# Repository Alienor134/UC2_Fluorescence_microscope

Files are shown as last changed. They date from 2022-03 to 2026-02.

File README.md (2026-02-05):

# Fluorescence microscope adapted with UC2 library





An open-source, modular LED-based fluorescence microscope with infinity optics. This system is capable of acquiring time-lapse videos from living cells inside an incubator and supports X/Y/Z/t acquisitions and fluorescent imaging.

**Intended Audience**: Researchers, engineers, microscopists interested in reducing the cost of hardware development for optical systems and produce quick prototypes. 

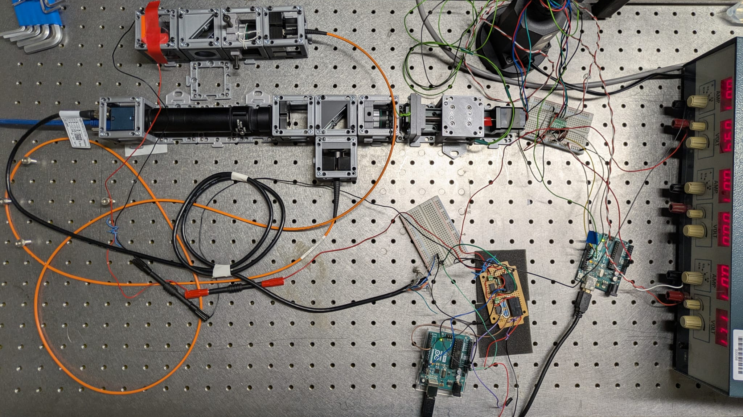
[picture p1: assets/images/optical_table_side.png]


## Documentation

Access the full [documentation website](https://alienor134.github.io/UC2_Fluorescence_microscope/docs)

## Repository Structure

- **Hardware**: CAD files in `INVENTOR/` (source) and `STL/` (3D printing). Specific hardware ca also be found in the submodules, in particular for different motorization options 
- **Software**: Control modules as Git submodules (`ControlCamera`, `ControlLight`, `ControlMotors`, `ControlSerial`)
- **Documentation**: Build guides, automation, and bills of materials in `docs/`

## Quick Start

```bash
# Clone the repository with submodules
git clone https://github.com/Alienor134/UC2_Fluorescence_microscope.git
cd UC2_Fluorescence_microscope
git submodule update --init --recursive
```

The instrument can run without specific software except the camera. The LED control and motor control are optional and can be replaced by manual actions. Still, for detailed setup instructions of the software, see [docs/automate.md](docs/automate.md)

---

## Interested in contributing to the project ? Read the following.

This project follows the [Open Source Hardware Association (OSHWA) definition](https://www.oshwa.org/definition/) of open-source hardware. All design files, documentation, and bills of materials are freely available. Modifications and derivatives are encouraged under the terms of the CERN-OHL-S-2.0 license.

If any file missing, raise an issue in Gtihub repository and we will address it.

### Licenses

#### Hardware License
The hardware designs (CAD files, STL files, and mechanical assemblies) are licensed under the **CERN Open Hardware Licence Version 1 (CERN-OHL-S-1.2)**. See [LICENSE](License.md) for full text. The license is inherited from the OpenUC2 project.

#### Software License
The control software modules are licensed under the **GNU General Public License v3.0 (GPL-3.0)** or later. See individual LICENSE files in each submodule directory.

#### Documentation License
Documentation is licensed under **Creative Commons Attribution-ShareAlike 4.0 International (CC BY-SA 4.0)**.

### Version Control Practice

- **Repository**: Git-based version control with full commit history
- **Submodule Structure**: This module is part of the UC2 Fluorescence Microscope parent repository
- **Versioning**: Semantic versioning (MAJOR.MINOR.PATCH)
- **Releases**: Archived on Zenodo

### Attribution Requirements

When using or modifying this software:

1. **Credit the original authors**: Aliénor Lahlou, Sony Computer Science Laboratories
2. **Maintain license notices**: Keep license-related headers in source files
3. **Document modifications**: Clearly state any changes made
4. **Share derivatives**: Derivatives must be released compatible license

### Contributing

Contributions are tracked through:
- Git commit history (automatic attribution)
- Pull requests on GitHub
- Contributor acknowledgments in release notes

The documentation is automatically generated via Github Pages and should be updated along modifications (folder [docs](https://github.com/Alienor134/UC2_Fluorescence_microscope/tree/main/docs)). Follow these [instructions](https://docs.github.com/en/pages/setting-up-a-github-pages-site-with-jekyll/testing-your-github-pages-site-locally-with-jekyll) to verify the changes locally before commit. 

--- 

## Current version

- **Current Version**: 1.0.0
- **Last Updated**: January 2026
- **Git Repository**: https://github.com/Alienor134/UC2_Fluorescence_microscope
- **Zenodo DOI**: https://doi.org/10.5281/zenodo.18483954

## Citation

If you use this microscope design in your research, please cite it properly. We have registered this project on Zenodo for permanent archival with a persistent DOI (https://doi.org/10.5281/zenodo.18483954).

## Acknowledgments

This project builds upon several open-source initiatives:

### Hardware Acknowledgments
- **[OpenUC2](https://github.com/openUC2/UC2-GIT)**: Base modular cube system and optical components.

### Software Acknowledgments
- **[pymmcore-plus](https://pymmcore-plus.github.io/pymmcore-plus/)** to facilitate working with Micro-manager backend in pure Python/C environments.
- **[ROMI project](https://github.com/romi)** (Sony CSL) providing open-source tools to control hardware with Arduino and Python.
- **[Sacred](https://github.com/IDSIA/sacred)** to organise automated experimental runs. 

## Attributions

This project is based on the [UC2 fluorescence microscope](https://github.com/openUC2/UC2_Fluorescence_microscope?tab=readme-ov-file) by OpenUC2, licensed under CERN-OHL-S v2.   
**Modifications**: light source (from laser to LED), motorized focus, software.
**Additions**: dual illumination, optical fiber injection, data management.

*This project is open-source and released under CERN-OHL-S-2.0 (hardware) and GPL-3.0 (software) licenses.*

---

## Cross-References and Navigation

### UC2 Fluorescence Microscope Project

- **Main Repository**: [UC2_Fluorescence_microscope](https://github.com/Alienor134/UC2_Fluorescence_microscope)
- **Documentation Home**: https://alienor134.github.io/UC2_Fluorescence_microscope/docs/
- **Build Instructions**: https://alienor134.github.io/UC2_Fluorescence_microscope/docs/build
- **Bill of Materials**: https://alienor134.github.io/UC2_Fluorescence_microscope/docs/bill_of_materials
- **Automation Guide**: https://alienor134.github.io/UC2_Fluorescence_microscope/docs/automate
- **Examples**: https://alienor134.github.io/UC2_Fluorescence_microscope/docs/example

### Related Control Modules

| Module | Purpose | Documentation |
|---|---|---|
| [ControlCamera](https://github.com/SonyCSLParis/ControlCamera) | Camera acquisition and control | [README](https://github.com/SonyCSLParis/ControlCamera/README.md) |
| [ControlLight](https://github.com/SonyCSLParis/ControlLight) | Laser and LED control | [README](https://github.com/SonyCSLParis/ControlLight/README.md) |
| [ControlMotors](https://github.com/SonyCSLParis/ControlMotors) | XYZ stage and motor control | [README](https://github.com/SonyCSLParis/ControlMotors/README.md) |
| [ControlSerial](https://github.com/SonyCSLParis/ControSerial)| Arduino-Python communication | [README](https://github.com/SonyCSLParis/ControSerial/README.md) |
| [Altar](https://github.com/DreamRepo/Altar) | Data management and visualization | [Documentation](https://dreamrepo.github.io/Altar/) |

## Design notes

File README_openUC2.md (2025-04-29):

<p align="left">

</p>

# openUC2 Fluorescence Microscope (infinity)
---

This is the repository for the laser-based fluorescence microscope with infinity optics. It is capable to acquire Time-Lapse videos from living cells inside an incubator.

The current version of the Z-stage is inspired by the flexure-bearing Z-stage from Richard Bowman's openflexure microscope design. Their open-source project can be found [here](https://openflexure.org). We also emphasize to use the [delta stage](https://openflexure.org/projects/deltastage/) where [UC2 provides an adapter](https://github.com/openUC2/UC2-GIT/tree/master/CAD/ASSEMBLY_CUBE_Openflexure_Deltastage) for our system.

The setup looks as follows:

<p align="center">
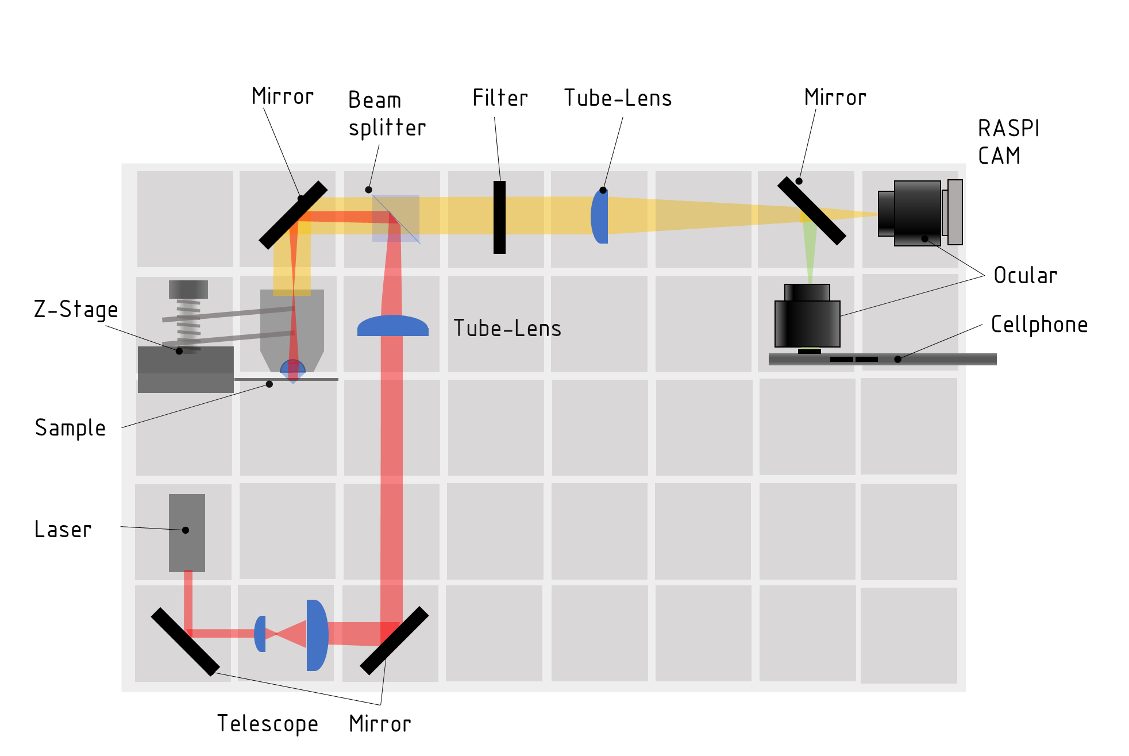
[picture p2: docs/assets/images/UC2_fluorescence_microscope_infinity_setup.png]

</p>

We use a high power entertainment laser to excite a specific fluorophore, where the emission signal is either filtered by a proper dichroic mirror cube (dichroic+filter) or a low-cost version of a simple 50/50 beamsplitter and an emission filter. The setup uses infinity optics and can either be used with a bare chip or a combination of cellphone camera (with lens) and an eyepiece to achieve proper imaging.

It is a very early developer version. Please feel free to contribute to the documentation and device development.

*Note:* The pictures on this site do not show the latest version of the Z-stage. Follow the respective assembly guidelines.

<p align="center">
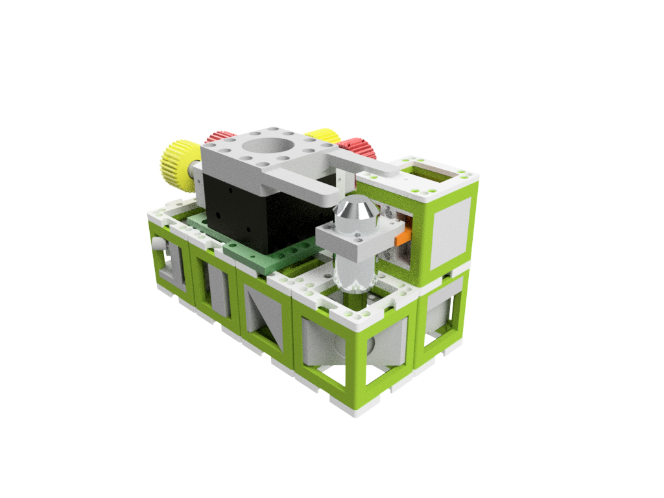
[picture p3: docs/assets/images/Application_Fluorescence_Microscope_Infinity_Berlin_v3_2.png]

</p>

***Features:***

* X/Y/Z/t Acquisitions possible
* Fluorescent imaging
* Quantitative Phase Imaging
* Modularized design
* Low-cost acquisition
* Based on off-the-shelf components
* Open-Source
* infinity corrected optics
* use of low-cost CMOS sensors possible

# Software
🢂 Find the software for this setup in our dedicated [UC2-Software-GIT](https://github.com/bionanoimaging/UC2-Software-GIT)

# Hardware

Below we describe how the device can be build and assembled in order to replicate the whole system as shown in the rendering above. One needs additional parts that can be found in the core [openUC2 repository](https://github.com/bionanoimaging/UC2-GIT).

### Parts for this setup

<p align="center">
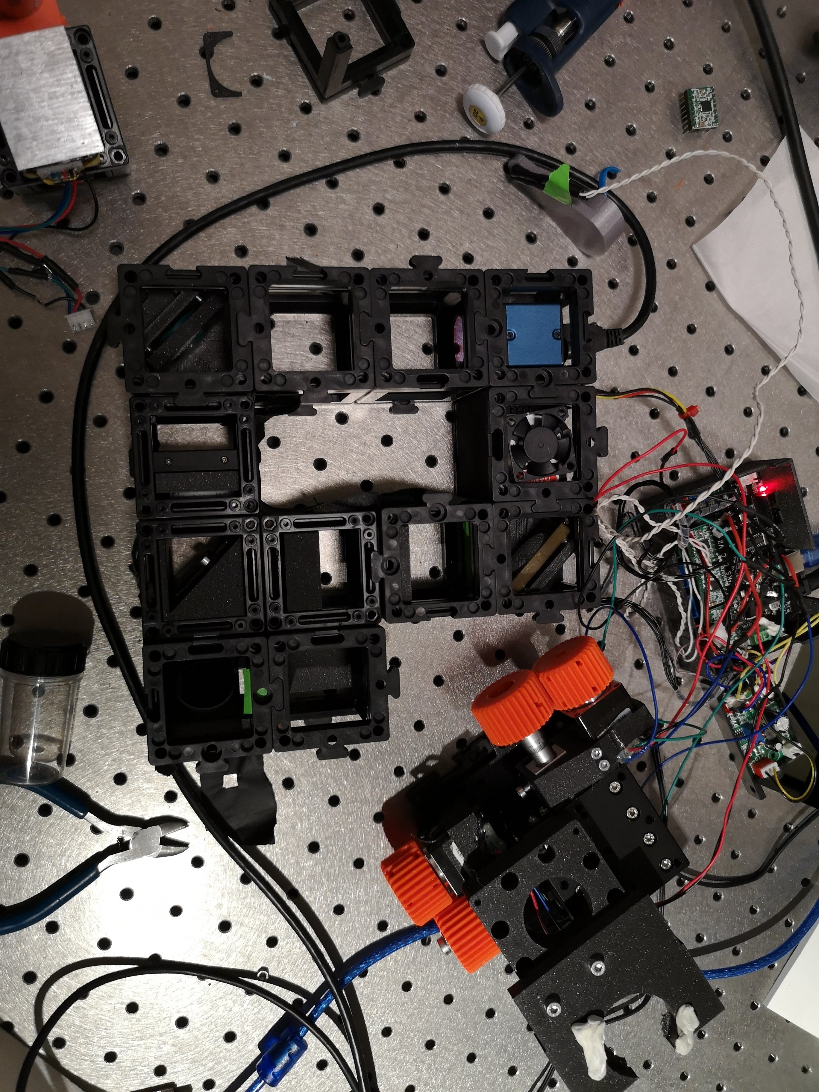
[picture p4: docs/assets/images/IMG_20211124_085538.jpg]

</p>

| Amount | Type  | Properties | Price | Source |
|----|----|----|----|----|
| 1 | Camera | Daheng Imaging MER2-230-168U3M | 500 € | Daheng Imaging [Link](https://www.machinevisionkamera.de/USB3-Bildverarbeitungskamera-2.3MP-Monochrome-Sony-IMX174-MER2-230-168U3M)|
| 1  | Camera | USB ALVIUM 1800 U -158 | 333 € | Allied Vision [Edmund Optics](https://www.edmundoptics.de/p/allied-vision-alvium-1800-u-158m-129-16mp-s-mount-usb-31-monochrome-camera/42981/) |
| 1 | Laser | 1× Laser Module, 635/637nm entertainment laser (laserlands.net, #3450, Dot Laser Module, 300mW, 50 Euro, China)  | 60 €| [Laserlands.net](https://www.laserlands.net/638nm-laser-500mw-laser-module-red-light-laser.html)|
| 1 | Emission Filter (we used on old Chroma, QE690/55!) | Thorlabs FEL0650 | 78 € | [Thorlabs](https://www.thorlabs.com/thorproduct.cfm?partnumber=FEL0650) |
| 1 | Dichroic Mirror | DMLP650 | 250 € | [Thorlabs](https://www.thorlabs.com/thorproduct.cfm?partnumber=DMLP650) |
| 1 | Shortpass Filter (cleanup)  | FES0650 | 78 € | [Thorlabs](https://www.thorlabs.com/thorproduct.cfm?partnumber=FES0650) |
| 2 | Mirrors 1 inch | Silver, protected mirror | 50 € | [Thorlabs](https://www.thorlabs.com/thorproduct.cfm?partnumber=PF10-03-P01) |
| 1 | Tube lense according to objective lens (imaging-side) | 80 mm for Allied Vision, 150 for Daheng Imaging, Achromat | 96 € | [Thoralbs](https://www.thorlabs.de/thorproduct.cfm?partnumber=AC254-080-A-ML)/[Thoralbs](https://www.thorlabs.de/thorproduct.cfm?partnumber=AC254-150-A-ML) |
| 1 | Tube Lens (illumination-side) | Achromat, f 156,4mm / ∅40,0mm  or  f 150 mm / ∅25,4mm | 5,9 € / 96 € | [PGI-Versand](https://astro-didaktik.de/achromat-2-linser-o-40-mm-f-156-4-mm.html)/[Thoralbs](https://www.thorlabs.de/thorproduct.cfm?partnumber=AC254-150-A-ML) |
| 1 | M3 Screws, DIN ISO 912, various (buy a set) | | ? | Würth |
| 1 | Microscope Objective lens | 1x Objective lens, No Name, 100x, NA1.25, 50 Euro, China | 100 € | [Aliexpress](https://de.aliexpress.com/item/4000200609554.html) |
| 1 | Beam Splitter Dichroic (Discontinued?) | Comar optics Dichro 740 IY als 45° | 40 € | Comar  |
| 1 | Filter Emission (Discontinued?) | Emissionsfilter 655 IY als 0° | 40 € | Comar |
| 200  | Magnets  | 5mm Ball Magnets, NEoxym  | 0,31 | [Magnetmax](https://www.magnetmax.de/Neodym-Kugelmagnete/Magnetkugel-Kugelmagnet-O-5-0-mm-Neodym-vernickelt-N40-haelt-400-g::158.html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) || 4 | Mirrors 1 inch | Thoralbs | ~50 | [Thorlabs](https://www.thorlabs.com/thorproduct.cfm?partnumber=PF10-03-P01) |  1x500 | Screws M3x12 | | ?  | [Würth](https://eshop.wuerth.de/Zylinderschraube-mit-Innensechskant-SHR-ZYL-ISO4762-88-IS25-A2K-M3X12/00843%20%2012.sku/de/DE/EUR/)

Find the complete [Bill-of-Materials here](UC2_Microscope_BillOfMaterial_STORM.xlsx)

## Modules

|  Name | Properties  |  Price | Link  | # |
|---|---|---|---|---|
|  Baseplate puzzle| - | 5€  | [Base-plate](https://github.com/openUC2/UC2-GIT/tree/master/CAD/ASSEMBLY_Baseplate/)  | ~20|
|  Module: Z-Stage | - | ?? €  | [Z-Stage](https://github.com/openUC2/UC2-GIT/tree/master/CAD/ASSEMBLY_CUBE_Z-STAGE_NEMA_MGN)  | 1|
| (Alternative) [Delta stage](https://openflexure.org/projects/deltastage/)  | Openflexure | ?? €  | [Deltastage](https://github.com/openUC2/UC2-GIT/tree/master/CAD/ASSEMBLY_CUBE_Openflexure_Deltastage)  | 1|
|  Module: Kinematic Mirror 45°  (THORLABS!) | - | 5€  | [Kinematic Mirror 45](https://github.com/openUC2/UC2-GIT/tree/master/CAD/ASSEMBLY_CUBE_Mirror_Kinematic_45)  | 2 |
|  Module: Alvium CMOS Camera  | Low-Cost Camera | 5€  | [Alvium Camera](https://github.com/openUC2/UC2-GIT/tree/master/CAD/ASSEMBLY_CUBE_AlliedVision_Alvium)  | 1|
| Alternative (better) Daheng Imaging IMX174 | SMLM Camera | 5€  | [Alvium Camera](https://github.com/openUC2/UC2-GIT/tree/master/CAD/ASSEMBLY_CUBE_AlliedVision_Alvium)  | 1 |
|  Module: Beamsplitter (dichroic)  | - | ??€  | [Dichroic Beam splitter](https://github.com/openUC2/UC2-GIT/tree/master/CAD/ASSEMBLY_CUBE_Dichroic_Beamsplitter)  | 1|
|  Module: Thorlabs + Lens (160mm, 80mm) | - | 5€  | [Thorlabs Insert](https://github.com/openUC2/UC2-GIT/tree/master/CAD/ASSEMBLY_CUBE_Thorlabs)  | 2 |
|  Module: Laser (Block) | - | 5€  | Just mount the laser on the insert using screws. | 2 |
|  Module: 45° Mirror  (Thorlabs) | - | 5€  | [Mirror](https://github.com/openUC2/UC2-GIT/tree/master/CAD/ASSEMBLY_CUBE_Mirror_45)  | 2 |

### Variants

We use various different XY Stages:

[**1. Micrometer XY-stage**](https://github.com/openUC2/UC2-MicronStage)

[**2. Aliexpress Microscop XY-stage**](https://github.com/openUC2/UC2-Motorized-XY-Table)

**3. Openflexure Stage**

### Electronics
🢂 Find more in the [Electronics section](https://github.com/openUC2/UC2-GIT/tree/master/ELECTRONICS)

## Setup variants

**Assembled Setups with a Jetson-driven mono camera:**

For more infos about the camera look [here](https://github.com/openUC2/UC2-GIT/tree/master/CAD/ASSEMBLY_CUBE_AlliedVision_Alvium)

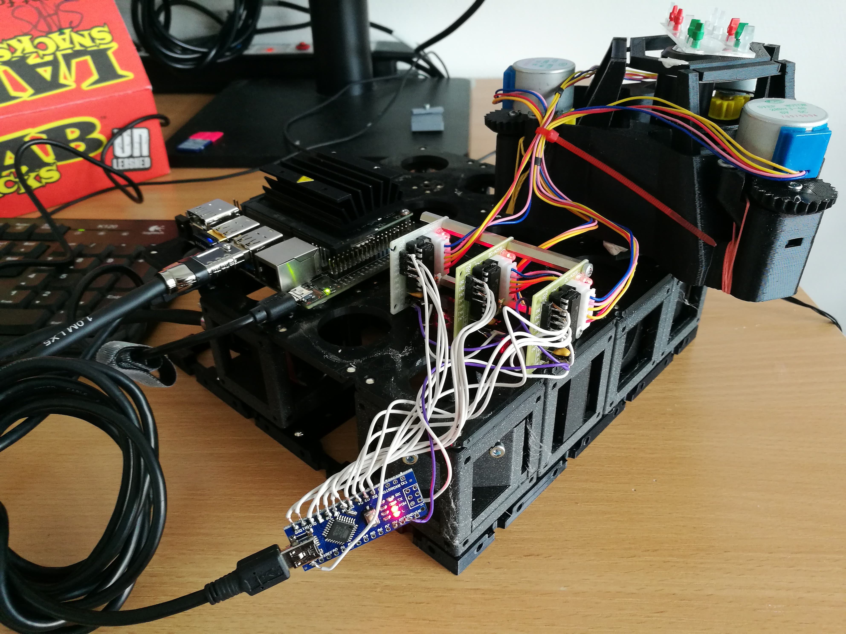
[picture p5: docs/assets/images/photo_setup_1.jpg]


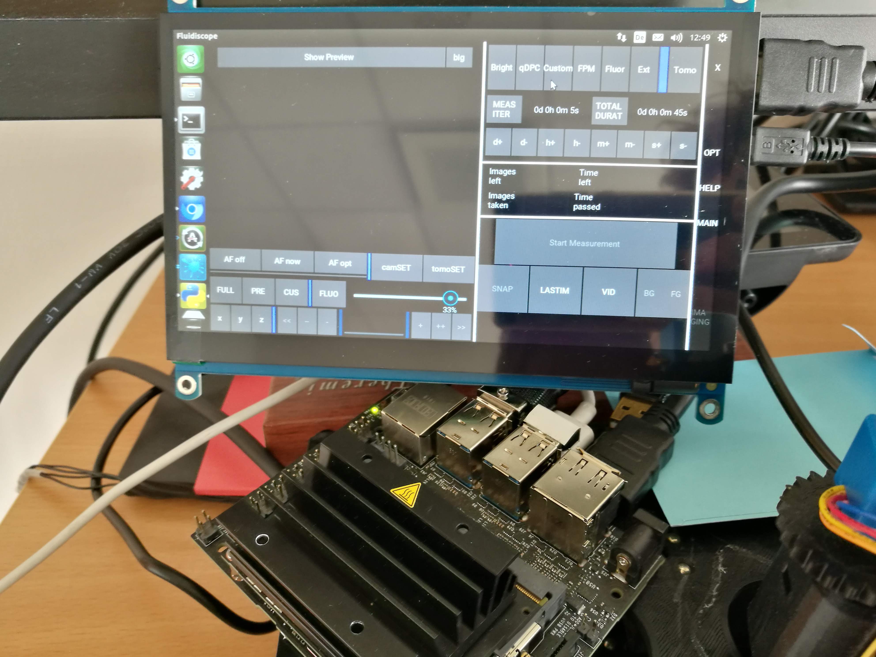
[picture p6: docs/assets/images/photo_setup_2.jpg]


## Setup

**Side View:**



**Top View:**

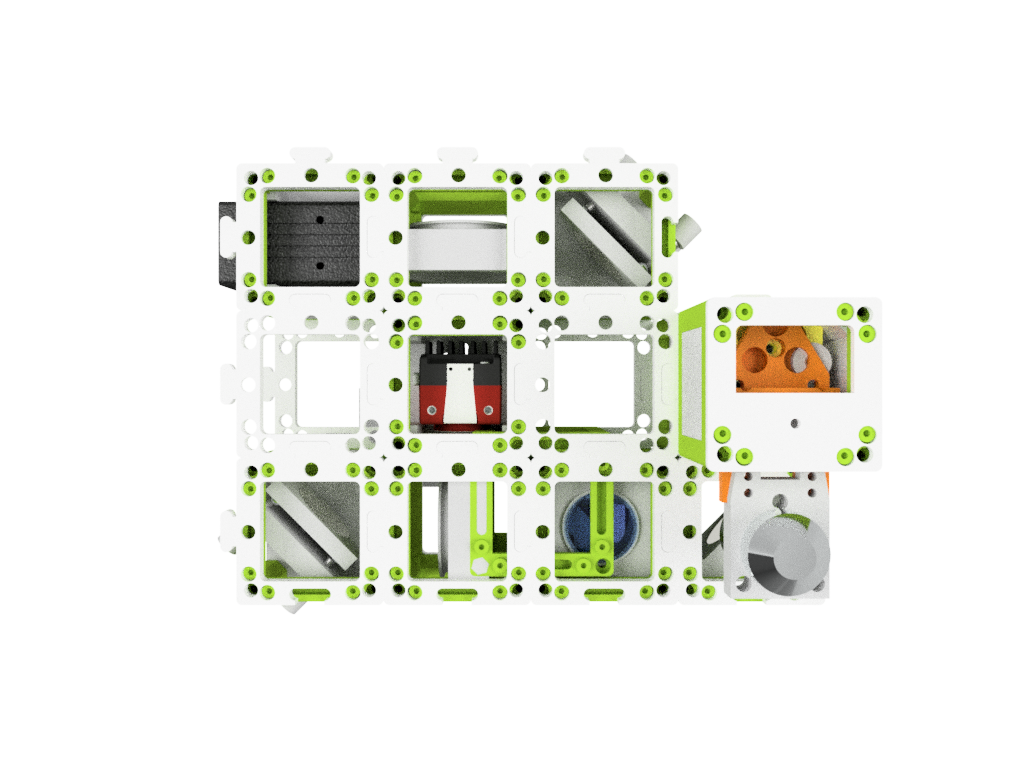
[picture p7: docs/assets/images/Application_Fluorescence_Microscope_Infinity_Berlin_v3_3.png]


**Backside View:**

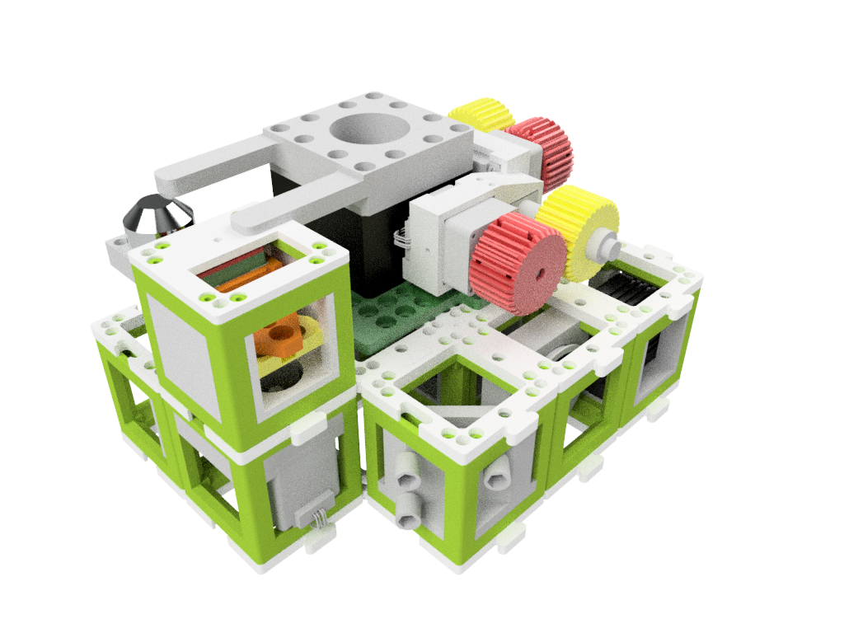
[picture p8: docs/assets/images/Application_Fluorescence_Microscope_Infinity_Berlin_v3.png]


**Find a little [Tutorial on how to make it work here](Tutorial.md)**

## Showcase
This is a set of ATTO 647 labelled *e.colis* provided by O. Helle from UiO imaged with a 100x, 1.25, a cellphone (Huawei P20 Pro, monochromatic camera, Freedcam) and a 635/637 nm exciation.

<p align="center">
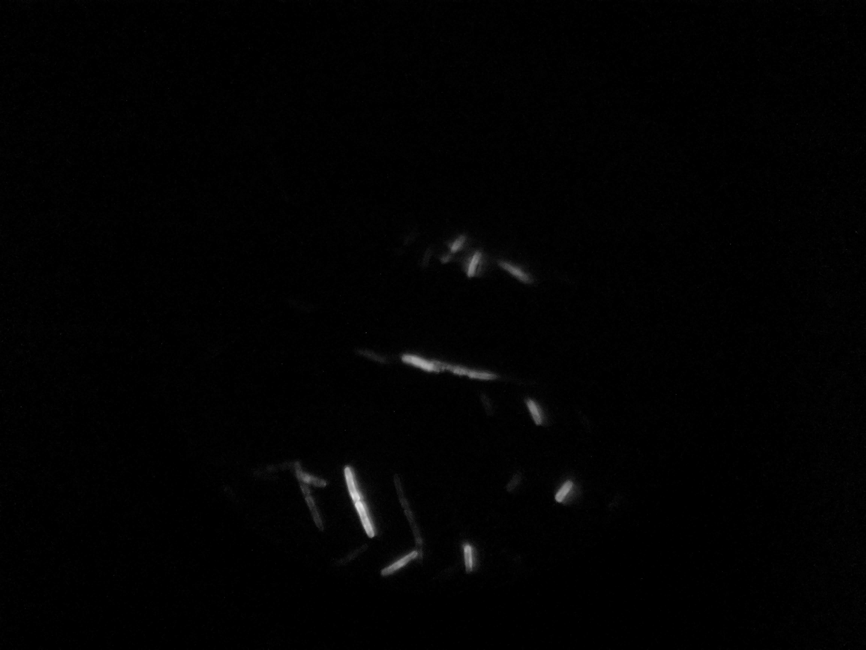
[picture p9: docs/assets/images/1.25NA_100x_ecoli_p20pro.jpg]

</p>

This is acquired with the Allied Vision Alvium 1500-158 and the new UC2 Nvidia Jetson Nano GUI. HeLa labelled with Alexa Fluor 647 Phal.

***Brightfield***
<p align="center">
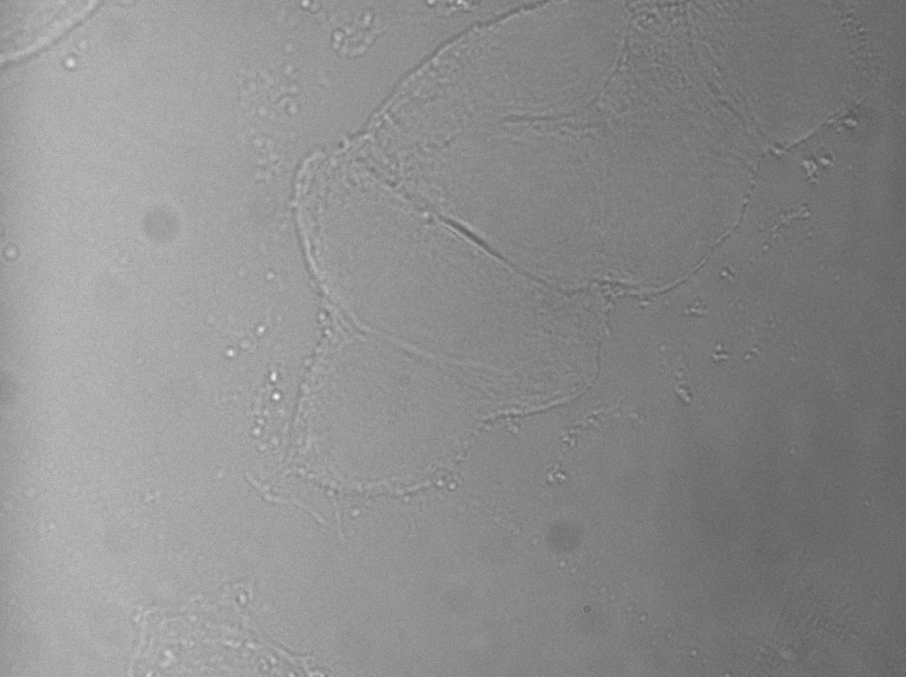
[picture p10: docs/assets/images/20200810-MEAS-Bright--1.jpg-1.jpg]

</p>

***Fluorescence***
<p align="center">
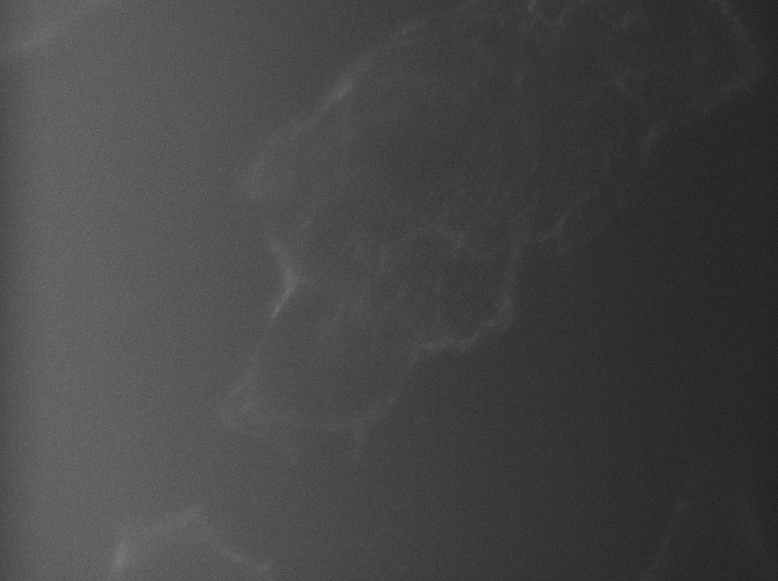
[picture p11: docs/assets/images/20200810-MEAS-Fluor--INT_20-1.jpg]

</p>

***Overlay***
<p align="center">
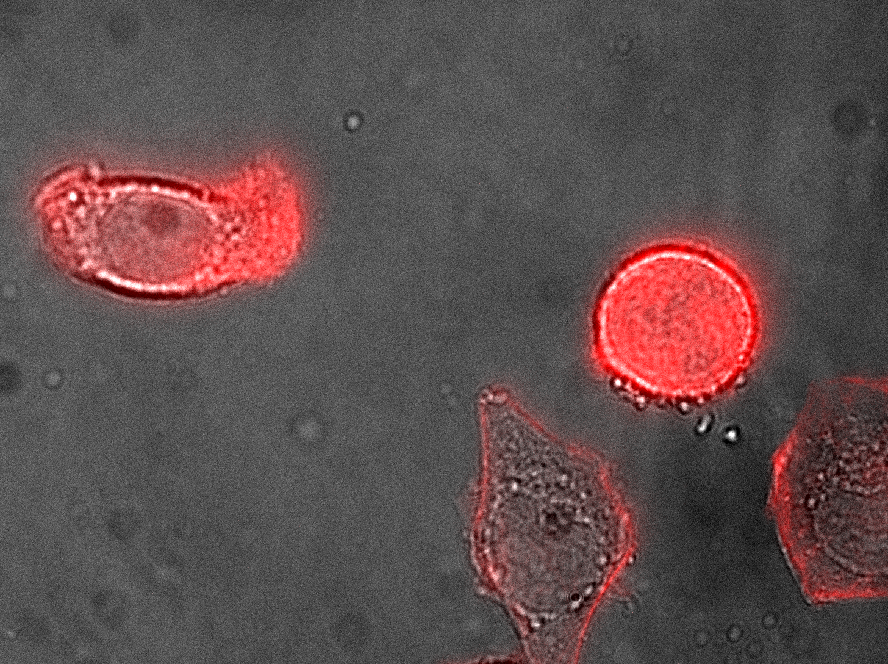
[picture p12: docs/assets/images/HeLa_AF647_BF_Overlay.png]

</p>

***Optical Setup***
<p align="center">

</p>

***ImSwitch Control Software***
<p align="center">
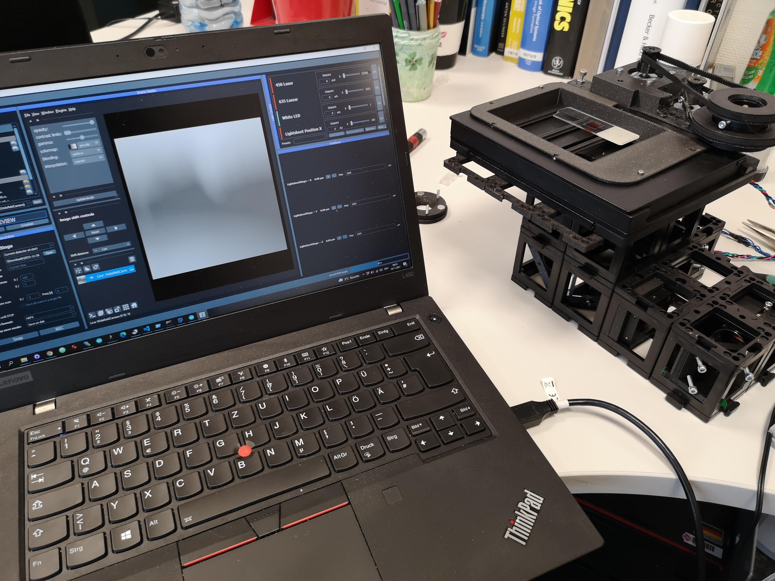
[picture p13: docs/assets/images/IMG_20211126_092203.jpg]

</p>

***SMLM Sample Holder***
<p align="center">
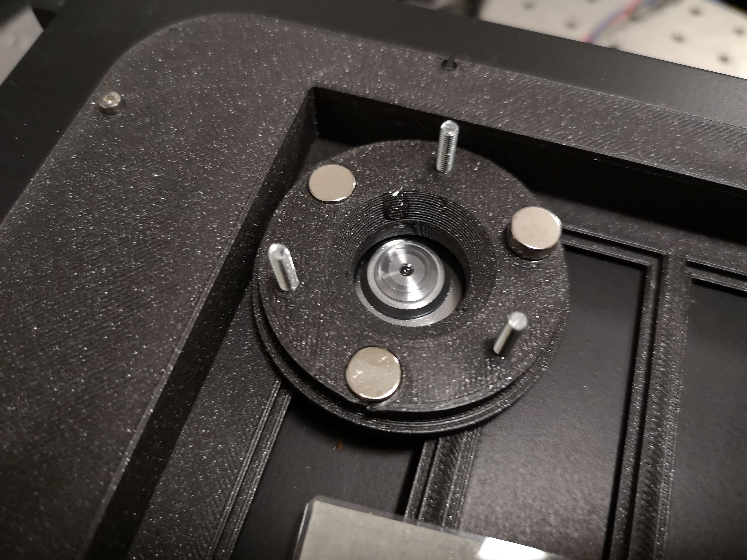
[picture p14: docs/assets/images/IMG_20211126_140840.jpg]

</p>

## Get Involved

This project is open-source so that anyone can get involved. You don't even have to learn CAD designing or programming. Find ways you can contribute in  [CONTRIBUTING](https://github.com/openUC2/UC2-GIT/blob/master/CONTRIBUTING.md)

## License and Collaboration

This project is open-source and is released under the CERN open hardware license. Our aim is to make the kits commercially available.
We encourage everyone who is using our Toolbox to share their results and ideas, so that the Toolbox keeps improving. It should serve as a easy-to-use and easy-to-access general purpose building block solution for the area of STEAM education. All the design files are generally for free, but we would like to hear from you how is it going.

You're free to fork the project and enhance it. If you have any suggestions to improve it or add any additional functions make a pull-request or file an issue.

Please find the type of licenses [here](https://github.com/openUC2/UC2-GIT/blob/master/License.md)

REMARK: All files have been designed using Autodesk Inventor 2019 (EDUCATION)

## Collaborating
If you find this project useful, please like this repository, follow us on Twitter and cite the webpage! :-)

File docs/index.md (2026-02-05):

---
layout: default
title: Introduction
nav_order: 1
---

# Introduction

 Reference: *Minimal reproduction and calibration of a fluorescence microscope for single-cell imaging*


*Picture of the final set-up*

> Source code: [UC2_Fluorescence_microscope on GitHub](https://github.com/Alienor134/UC2_Fluorescence_microscope)

## Navigation
- [Introduction](index.md)
- [Bill of Materials](bill_of_materials.md)
- [Build Instructions](build.md)
- [Software](automate.md)

---

# Purpose

Microscopy is a critical experimental tool in life sciences. However, when attempting to reproduce or scale-up a published method, researchers often meet difficulties in implementing specific protocols, often because they do not have full control over the hardware and software. 

To address these challenges, we present a modular open-source hardware and software pipeline that integrates automation and database management. 

We provide comprehensive guidance on building and calibrating the microscope hardware, implementing automation, and data analysis and storage methods. The highly modular Python software we introduce facilitate customization and reusability beyond microscopy, empowering researchers and engineers to adapt components for other scientific applications.

The microscope presented here is a simplified and open-source version of the microscope used in [this publication](https://doi.org/10.1101/2025.01.23.633867). The 3D structure was derived from the [Open-UC2](https://openuc2.com/) library.

In this repository we provide: 
- A [bill of materials](bill_of_materials.md) to reproduce the microscope 
- [Build instructions](build)
- Python packages to use the library: they each have their specific documentation
- [Software](automate.md) summary with support codes

# License

**Hardware License**

The hardware designs (CAD files, STL files, and mechanical assemblies) are licensed under the CERN Open Hardware Licence Version 1.2 (CERN-OHL-S-1.2). See LICENSE for full text.

**Software License**

The control software modules are licensed under the GNU General Public License v3.0 (GPL-3.0) or later. See individual LICENSE files in each submodule directory.

**Documentation License**

Documentation is licensed under Creative Commons Attribution-ShareAlike 4.0 International (CC BY-SA 4.0).

# Attributions

This project is based on the [UC2 fluorescence microscope](https://github.com/openUC2/UC2_Fluorescence_microscope?tab=readme-ov-file) by OpenUC2, licensed under CERN-OHL-S v2.   
**Modifications**: light source (from laser to LED), motorized focus, software.
**Additions**: dual illumination, optical fiber injection, data management.
The original authors do not endorse this version.

# Contributing

The guidelines to contribute to the project (including versionning and attribution statements) are listed in the [README](https://github.com/Alienor134/UC2_Fluorescence_microscope/blob/main/README.md) page of this project.

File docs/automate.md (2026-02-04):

# Software

thumbnails

## Summary of the available software

[ControlSerial](https://github.com/Alienor134/UC2_Fluorescence_microscope) - Python serial interface  
[ControlMotors](https://github.com/Alienor134/UC2_Fluorescence_microscope) - Motor control  
[ControlCamera](https://github.com/Alienor134/UC2_Fluorescence_microscope) - Camera acquisition interface  
[ControlLight](https://github.com/Alienor134/UC2_Fluorescence_microscope) - LED and laser control  

## Install instructions

Begin by installing the packages in a virtual environment. For more information on why virtual environments matter, refer to [this page](https://github.com/Alienor134/Teaching/blob/master/Python/Tutorials/Install_Anaconda_Jupyter.md).

```bash
git clone https://github.com/Alienor134/UC2_Fluorescence_microscope.git
cd UC2_Fluorescence_microscope
git submodule update --init --recursive
conda create -n control python=3.10
conda activate control
cd ControlSerial
pip install -e .
cd ..
cd ControlMotors
pip install -e .
cd ..
cd ControlCamera
pip install -e .
cd ..
cd ControlLight
pip install -e .
```

Install the libraries required for Arduino following the README instructions in [ControlSerial](https://github.com/SonyCSLParis/ControlSerial) and [ControlMotors](https://github.com/SonyCSLParis/ControlMotors).

## [optional]
If you want to install a data management strategy, implement the data management directly at the instrument level using [Sacred](https://sacred.readthedocs.io/en/stable/). Then use the [Altar](https://dreamrepo.github.io/Altar/) suite to interact with the data. 

## Example of use
For an example of project using this software you can refer to [this page](https://alienor134.github.io/UC2_Fluorescence_microscope/docs/example).

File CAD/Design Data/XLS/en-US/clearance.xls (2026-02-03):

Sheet: Ansi Unified Screw Threads
I | Sort Order -1
Fastener Type | Size | Shaft Diameters |  |  | Head Dimensions
 |  | Close | Normal | Loose | Diameter | Depth/Angle | Head Type
Flat Head Machine Screw (82) | #0 | 0.0635 | 0.07 | 0.073 | 0.119 | 82 | 2
Flat Head Machine Screw (82) | #1 | 0.076 | 0.081 | 0.089 | 0.146 | 82 | 2
Flat Head Machine Screw (82) | #2 | 0.089 | 0.096 | 0.1065 | 0.172 | 82 | 2
Flat Head Machine Screw (82) | #3 | 0.104 | 0.11 | 0.12 | 0.199 | 82 | 2
Flat Head Machine Screw (82) | #4 | 0.116 | 0.1285 | 0.136 | 0.225 | 82 | 2
Flat Head Machine Screw (82) | #5 | 0.1285 | 0.136 | 0.154 | 0.252 | 82 | 2
Flat Head Machine Screw (82) | #6 | 0.144 | 0.1495 | 0.1695 | 0.279 | 82 | 2
Flat Head Machine Screw (82) | #8 | 0.1695 | 0.177 | 0.1935 | 0.332 | 82 | 2
Flat Head Machine Screw (82) | #10 | 0.196 | 0.201 | 0.221 | 0.385 | 82 | 2
Flat Head Machine Screw (82) | #12 | 0.221 | 0.228 | 0.246 | 0.438 | 82 | 2
Flat Head Machine Screw (82) | 1/4 | 0.257 | 0.266 | 0.2812 | 0.507 | 82 | 2
Flat Head Machine Screw (82) | 5/16 | 0.323 | 0.332 | 0.3437 | 0.635 | 82 | 2
Flat Head Machine Screw (82) | 3/8 | 0.386 | 0.397 | 0.4062 | 0.762 | 82 | 2
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

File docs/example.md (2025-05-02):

## Example of project

You can find an example of a project using the fluorescence microscope [here](https://github.com/Alienor134/CSL-forge/tree/main). It corresponds to the code used for the project [manuscript - TODO]().

- The folder [CSL-experiments](https://github.com/Alienor134/CSL-forge/tree/main/CSL-experiments) explains how to connect the fluorescence microscope to the database framework [Sacred](https://github.com/IDSIA/sacred) and store the data in MongoDB. It contains several examples of codes used to generate the raw data for the [manuscript - TODO]().

- The folder [CSL-analysis](https://github.com/Alienor134/CSL-forge/tree/main/CSL-analysis) access the database using the Python package [Incense](https://github.com/JarnoRFB/incense) and show how to analyse the data. It corresponds to the data presented in [manuscript - TODO]().

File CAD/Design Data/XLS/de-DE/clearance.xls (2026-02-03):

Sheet: ANSI UST
I | Reihenfolge -1
Schraubentyp | Größe | Wellendurchmesser |  |  | Schraubenkopfbemaßungen
 |  | Schließen | Normal | Grob | Durchmesser | Tiefe/Winkel | Schraubenkopftyp
Flachkopfmaschinenschraube (82) | #0 | 0.0635 | 0.07 | 0.073 | 0.119 | 82 | 2
Flachkopfmaschinenschraube (82) | #1 | 0.076 | 0.081 | 0.089 | 0.146 | 82 | 2
Flachkopfmaschinenschraube (82) | #2 | 0.089 | 0.096 | 0.1065 | 0.172 | 82 | 2
Flachkopfmaschinenschraube (82) | #3 | 0.104 | 0.11 | 0.12 | 0.199 | 82 | 2
Flachkopfmaschinenschraube (82) | #4 | 0.116 | 0.1285 | 0.136 | 0.225 | 82 | 2
Flachkopfmaschinenschraube (82) | #5 | 0.1285 | 0.136 | 0.154 | 0.252 | 82 | 2
Flachkopfmaschinenschraube (82) | #6 | 0.144 | 0.1495 | 0.1695 | 0.279 | 82 | 2
Flachkopfmaschinenschraube (82) | #8 | 0.1695 | 0.177 | 0.1935 | 0.332 | 82 | 2
Flachkopfmaschinenschraube (82) | #10 | 0.196 | 0.201 | 0.221 | 0.385 | 82 | 2
Flachkopfmaschinenschraube (82) | #12 | 0.221 | 0.228 | 0.246 | 0.438 | 82 | 2
Flachkopfmaschinenschraube (82) | 1/4 | 0.257 | 0.266 | 0.2812 | 0.507 | 82 | 2
Flachkopfmaschinenschraube (82) | 5/16 | 0.323 | 0.332 | 0.3437 | 0.635 | 82 | 2
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

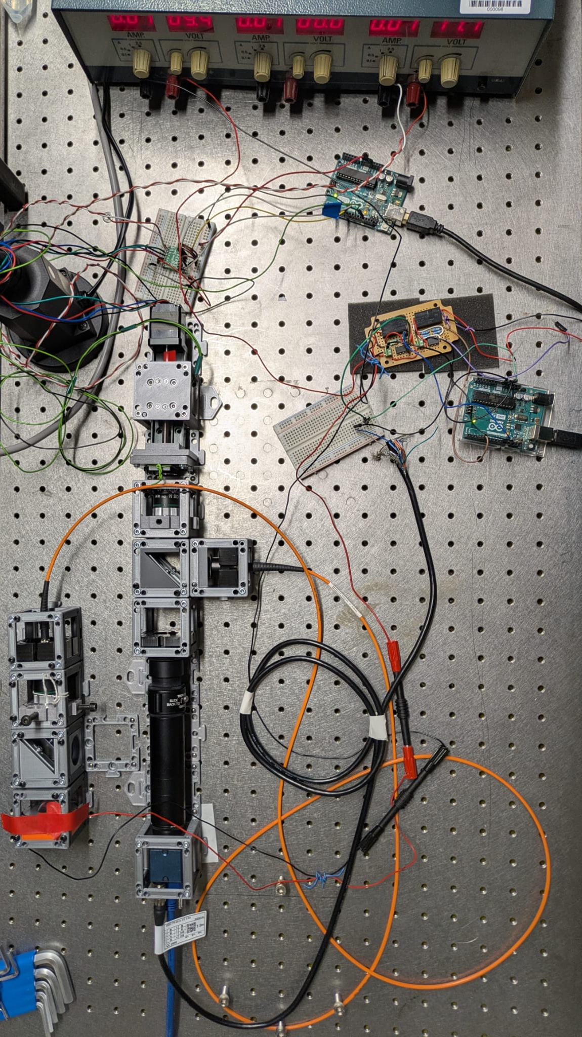
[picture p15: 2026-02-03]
assets/images/optical_table.png

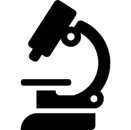
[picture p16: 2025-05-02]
assets/images/E.png

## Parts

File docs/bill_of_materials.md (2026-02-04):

---
layout: default
title: Bill of materials
nav_order: 2
---

# Bill of materials

### Hardware :gear:

| Component| Quantity |  Price per unit | Example|  
|---|:---:|---:|---:|
| High power LED blue 470 nm |  1 | 2 € | [Mouser](https://www.mouser.fr/ProductDetail/997-LXZ1PB01)|  
| High power LED purple 405 nm| 1 | 6 € | [Mouser](https://www.mouser.fr/ProductDetail/997-LHUV0405A065)|  
| PCB star Luxeon Z| 2 | 1 € | [LED mounting bases](https://led-mounting-bases.com/fr/mcpcb-pour-led/340-star-mcpcb-for-1-led-lumileds-luxeon-z-es.html)|
| Band-pass filter 475 nm|1 | 146 €  | [FBH470-10](https://www.thorlabs.com/newgrouppage9.cfm?objectgroup_id=1860&pn=FBH470-10)|  
| Band pass filter 390 nm| 1| 27 € |[390 GB 25](https://www.comaroptics.com/components/filters/glass-colour-filters)| 
| Band-pass filter 475 nm|1 | 146 €  | [FBH470-10](https://www.thorlabs.com/newgrouppage9.cfm?objectgroup_id=1860&pn=FBH470-10)|  
| Band-pass filter 525 nm|1 | 325 €  | [ET525/36](https://www.chroma.com/products/parts/et525-36m)|
| Band-pass filter 675 nm|1 | 333 €  | [ET675/90](https://www.ahf.de/en/products/spectral-analysis-photonic/optical-filters/individual-filters/bandpass-filters/600-699-nm/2449/675/90-et-bandpass)| 
| High pass filter 480 nm| 1| 45 € |[480 IY 125](https://www.comaroptics.com/components/filters/dichroic-filters/long-pass-dichroic-filters)| 
| High pass filter 580 nm| 1| 45 € |[580 IY 125](https://www.comaroptics.com/components/filters/dichroic-filters/long-pass-dichroic-filters)| 
| Asphreic condenser lens focal 16 mm | 2 | 18 € | [Thorlabs](https://www.thorlabs.de/thorproduct.cfm?partnumber=ACL25416U) |  
| Optical Fiber 400 µm 0.5 NA | 1 | 81 € | [Thorlabs](https://www.thorlabs.com/thorproduct.cfm?partnumber=M45L02) |  
| Microscope objective | 1 | --€ | [--](--)|  
| SMA fiber adaptater | 2 |29 € | [Thorlabs](https://www.thorlabs.com/thorproduct.cfm?partnumber=SM1SMA#ad-image-0)|
| RECOM RCD 24/1.2| 2 |28 € | [Mouser](https://www.mouser.fr/ProductDetail/RECOM-Power/RCD-24-120-W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])|
| potentiometer | 2 |--€ | [--](--)|

You will also need an LED-cooling system: it can be a copper plate, a radiator, a cooling fan. 

### UC2 parts

All the design files to build the microscope can be found in this [repository](https://github.com/Alienor134/UC2_Fluorescence_microscope/tree/main/STL). If you wish to edit the designs, the original CAD files are also available [here](https://github.com/Alienor134/UC2_Fluorescence_microscope/tree/main/CAD).

Link             |  Image of the part
:-------------------------:|:-------------------------:
[Base Plate puzzle](https://github.com/openUC2/UC2-GIT/tree/master/CAD/ASSEMBLY_Baseplate)  | 
[CUBE Base](https://github.com/openUC2/UC2-GIT/tree/master/CAD/ASSEMBLY_CUBE_Base)  |  
[LED Star](https://github.com/openUC2/UC2-GIT/tree/master/CAD/ASSEMBLY_CUBE_LED) | 
[Lens (cylindrical)](https://github.com/openUC2/UC2-GIT/tree/master/CAD/ASSEMBLY_CUBE_Lens_CYLINDRICAL) | 
[Dichroic Beam splitter](https://github.com/openUC2/UC2-GIT/tree/master/CAD//ASSEMBLY_CUBE_Dichroic_Beamsplitter) | 
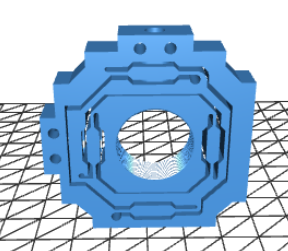
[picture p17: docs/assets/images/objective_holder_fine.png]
[objective holder](https://github.com/openUC2/UC2_OpenFiberCoupler#logo) | [](https://github.com/openUC2/UC2_OpenFiberCoupler#logo)
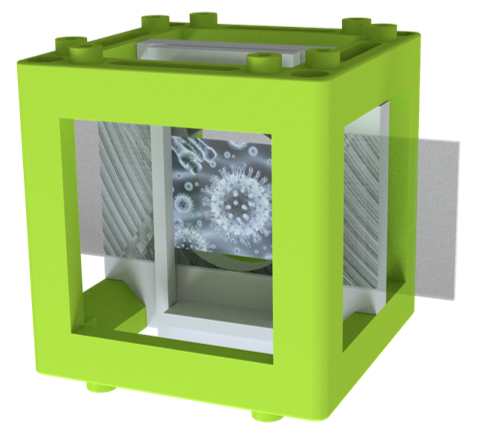
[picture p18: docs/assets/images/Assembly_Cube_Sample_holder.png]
[Generic Sample Holder](https://github.com/openUC2/UC2-GIT/tree/master/CAD/ASSEMBLY_CUBE_Sample_Holder) | [](https://github.com/openUC2/UC2-GIT/tree/master/CAD/ASSEMBLY_CUBE_Sample_Holder)
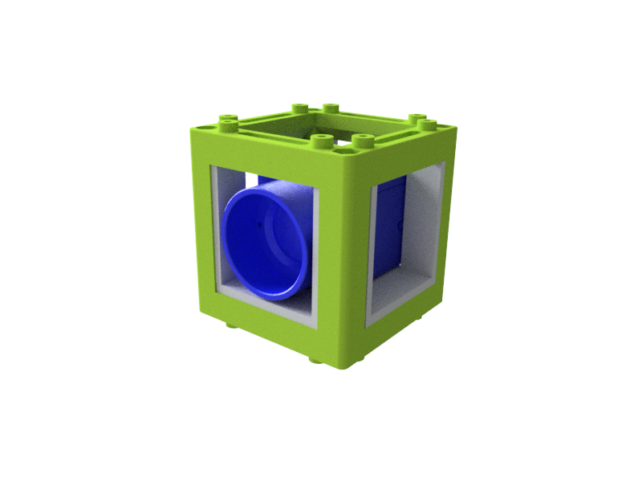
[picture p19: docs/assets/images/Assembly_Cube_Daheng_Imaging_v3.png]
[Camera Cube (Allied Vision Alvium)](https://github.com/openUC2/UC2-GIT/tree/master/CAD/ASSEMBLY_CUBE_Daheng_Imaging) | [](https://github.com/openUC2/UC2-GIT/tree/master/CAD/ASSEMBLY_CUBE_Daheng_Imaging)
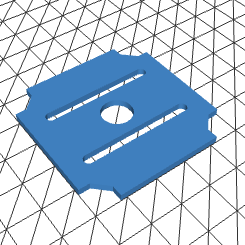
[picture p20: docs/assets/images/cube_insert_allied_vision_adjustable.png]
[Camera Insert Allied Vision Alvium adjustable](https://github.com/openUC2/UC2-GIT/blob/master/CAD/RAW/STL/20_Cube_insert_AlliedVision_Alvium_adjustable_v3.stl) | [](https://github.com/openUC2/UC2-GIT/blob/master/CAD/RAW/STL/20_Cube_insert_AlliedVision_Alvium_adjustable_v3.stl)

## Tools

- Soldering station
- hot plate
- drill (for the copper plate to cool-down the LED)

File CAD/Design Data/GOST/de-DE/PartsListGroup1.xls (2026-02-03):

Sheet: Лист 1
Инв. № подл |  |  |  | Подп. и дата | Взам. инв. № | Инв. № дубл. |  |  | Подп. и дата
Формат | Зона | Поз. | Обозначение |  |  |  | Наименование |  |  |  |  |  | Кол. на исполнение
 |  |  |  |  |  |  |  |  |  |  |  | Лит.
 |  |  |  |  |  |  |  |  |  |  |  | Код
 |  |  |  |  |  |  |  | Изм. | Лист | № докум | Подпись |  | Дата
 |  |  |  |  |  |  |  | Разраб.
 |  |  |  |  |  |  |  | Пров.
 |  |  |  |  |  |  |  | Н.контр
 |  |  |  |  |  |  |  | Утв.
 |  |  |  |  |  |  |  |  |  |  |  |  |  | Копировал

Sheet: Лист 2
Инв. № подл |  |  |  | Подп. и дата | Взам. инв. № | Инв. № дубл. |  |  | Подп. и дата
Формат | Зона | Поз. | Обозначение |  |  |  | Наименование |  |  |  |  | Кол. на исполнение
 |  |  |  |  |  |  |  | Изм. | Лист | № докум. | Подп. | Дата
 |  |  |  |  |  |  |  |  |  |  |  |  | Копировал
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

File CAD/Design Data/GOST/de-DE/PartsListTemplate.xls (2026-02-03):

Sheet: Лист 1
 | Формат | Зона |  | Поз. |  | Обозначение |  |  |  | Наименование |  |  |  | Кол. | Приме-чание
Подп. и дата
Инв. № дубл.
Взам. инв. №
Подп. и дата
 | Изм. |  | Лист |  | № докум |  | Подпись | Дата
Инв. № подл | Разраб. |  |  |  |  |  |  |  |  |  | Литера |  | Лист |  |  | Листов
 | Пров.
 | Н.контр
 | Утв.
 |  |  |  |  |  |  |  |  | Копировал |  |  | Формат А4

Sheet: Лист 2
 | Формат | Зона |  | Поз. |  | Обозначение |  |  |  | Наименование |  | Кол. | Приме-чание
Подп. и дата
Инв. № дубл.
Взам. инв. №
Подп. и дата
Инв. № подл
 | Изм. |  | Лист |  | № докум. |  | Подп. |  | Дата
 |  |  |  |  |  |  |  | Копировал |  |  | Формат А4
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

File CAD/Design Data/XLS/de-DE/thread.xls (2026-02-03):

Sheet: Inch Tapping Threads
I Q X | Zoll-Blechschraubgewinde |  | Sort Order - 5 |  | External |  |  |  |  |  |  | Internal
 |  |  |  |  |  | Major Dia |  | Pitch Dia |  | Minor Dia |  |  | Minor Dia |  | Pitch Dia |  | Major Dia |  | Tap Drill
Size | Size Suffix | Thread Designation | Custom Thread Designation | TPI | Class | Max | Min | Max | Min | Max | Min | Class | Min | Max | Min | Max | Min | Max | Basic
0.0600 |  | 0-48 | 0-48 | 48 | 2B | 0.0600 | 0.0540 | 0.0480 | 0.0435 | 0.0360 | 0.0330
0.0730 |  | 1-42 | 1-42 | 42 | 2B | 0.0750 | 0.0690 | 0.0620 | 0.0575 | 0.0490 | 0.0460
0.0860 |  | 2-32 | 2-32 | 32 | 2B | 0.0880 | 0.0820 | 0.0760 | 0.0710 | 0.0640 | 0.0600
0.0990 |  | 3-28 | 3-28 | 28 | 2B | 0.1010 | 0.0950 | 0.0880 | 0.0830 | 0.0750 | 0.0710
0.1120 |  | 4-24 | 4-24 | 24 | 2B | 0.1140 | 0.1080 | 0.1000 | 0.0950 | 0.0860 | 0.0820
0.1250 |  | 5-20 | 5-20 | 20 | 2B | 0.1300 | 0.1230 | 0.1120 | 0.1065 | 0.0940 | 0.0900
0.1380 |  | 6-20 | 6-20 | 20 | 2B | 0.1390 | 0.1320 | 0.1215 | 0.1155 | 0.1040 | 0.0990
0.1510 |  | 7-19 | 7-19 | 19 | 2B | 0.1540 | 0.1470 | 0.1345 | 0.1280 | 0.1150 | 0.1090
0.1640 |  | 8-18 | 8-18 | 18 | 2B | 0.1660 | 0.1590 | 0.1440 | 0.1375 | 0.1220 | 0.1160
0.1900 |  | 10-16 | 10-16 | 16 | 2B | 0.1890 | 0.1820 | 0.1650 | 0.1585 | 0.1410 | 0.1350
0.2160 |  | 12-14 | 12-14 | 14 | 2B | 0.2150 | 0.2080 | 0.1895 | 0.1825 | 0.1640 | 0.1570
0.2420 |  | 14-14 | 14-14 | 14 | 2B | 0.2410 | 0.2340 | 0.2130 | 0.2060 | 0.1850 | 0.1780
0.2500 |  | 1/4-14 | 1/4-14 | 14 | 2B | 0.2460 | 0.2370 | 0.2190 | 0.2110 | 0.1920 | 0.1850
0.3125 |  | 5/16-12 | 5/16-12 | 12 | 2B | 0.3150 | 0.3060 | 0.2795 | 0.2710 | 0.2440 | 0.2360
0.3750 |  | 3/8-12 | 3/8-12 | 12 | 2B | 0.3800 | 0.3710 | 0.3445 | 0.3350 | 0.3090 | 0.2990
0.4375 |  | 7/16-10 | 7/16-10 | 10 | 2B | 0.4400 | 0.4290 | 0.3995 | 0.3890 | 0.3590 | 0.3490
0.5000 |  | 1/2-10 | 1/2-10 | 10 | 2B | 0.5040 | 0.4930 | 0.4635 | 0.4530 | 0.4230 | 0.4130

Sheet: Metric Forming Screw Threads
M P X | Metrisch geform. Schraubgewinde |  | Sort Order - 6 |  | External |  |  |  |  |  |  | Internal
 |  |  |  |  |  | Major Dia |  | Pitch Dia |  | Minor Dia |  |  | Minor Dia |  | Pitch Dia |  | Major Dia |  | Tap Drill
Size | Size Suffix | Thread Designation | Custom Thread Designation | Pitch | Class | Max | Min | Max | Min | Max | Min | Class | Min | Max | Min | Max | Min | Max | Basic
1.5 |  | 1.5x0.5 | 1.5x0.5 | 0.5 | 6g | 1.520 | 1.380 | 1.215 | 1.110 | 0.910 | 0.840
1.5 |  | ST1.5x0.5 | ST1.5x0.5 | 0.5 | 6g | 1.520 | 1.380 | 1.215 | 1.110 | 0.910 | 0.840
1.9 |  | 1.9x0.6 | 1.9x0.6 | 0.6 | 6g | 1.900 | 1.760 | 1.570 | 1.465 | 1.240 | 1.170
1.9 |  | ST1.9x0.6 | ST1.9x0.6 | 0.6 | 6g | 1.900 | 1.760 | 1.570 | 1.465 | 1.240 | 1.170
2.2 |  | 2.2x0.8 | 2.2x0.8 | 0.8 | 6g | 2.240 | 2.100 | 1.935 | 1.810 | 1.630 | 1.520
2.2 |  | ST2.2x0.8 | ST2.2x0.8 | 0.8 | 6g | 2.240 | 2.100 | 1.935 | 1.810 | 1.630 | 1.520
2.6 |  | 2.6x0.9 | 2.6x0.9 | 0.9 | 6g | 2.570 | 2.430 | 2.235 | 2.115 | 1.900 | 1.800
2.6 |  | ST2.6x0.9 | ST2.6x0.9 | 0.9 | 6g | 2.570 | 2.430 | 2.235 | 2.115 | 1.900 | 1.800
2.9 |  | 2.9x1 | 2.9x1 | 1 | 6g | 2.900 | 2.760 | 2.540 | 2.420 | 2.180 | 2.080
2.9 |  | 2.9x1.1 | 2.9x1.1 | 1.1 | 6g | 2.900 | 2.760 | 2.540 | 2.420 | 2.180 | 2.080
2.9 |  | ST2.9x1.1 | ST2.9x1.1 | 1.1 | 6g | 2.900 | 2.760 | 2.540 | 2.420 | 2.180 | 2.080
2.9 |  | 2.9x1.3 | 2.9x1.3 | 1.3 | 6g | 2.900 | 2.720 | 2.540 | 2.355 | 1.890 | 1.700
2.9 |  | 2.9x1.4 | 2.9x1.4 | 1.4 | 6g | 2.900 | 2.720 | 2.340 | 2.175 | 1.780 | 1.630
3.3 |  | 3.3x1.3 | 3.3x1.3 | 1.3 | 6g | 3.300 | 3.120 | 2.795 | 2.665 | 2.290 | 2.210
3.3 |  | ST3.3x1.3 | ST3.3x1.3 | 1.3 | 6g | 3.300 | 3.120 | 2.795 | 2.665 | 2.290 | 2.210
3.5 |  | 3.5x1.3 | 3.5x1.3 | 1.3 | 6g | 3.530 | 3.350 | 3.085 | 2.930 | 2.640 | 2.510
3.5 |  | ST3.5x1.3 | ST3.5x1.3 | 1.3 | 6g | 3.530 | 3.350 | 3.085 | 2.930 | 2.640 | 2.510
3.5 |  | 3.5x1.6 | 3.5x1.6 | 1.6 | 6g | 3.530 | 3.350 | 2.920 | 2.755 | 2.310 | 2.160
3.5 |  | 3.5x3.2 | 3.5x3.2 | 3.2 | 6g | 3.530 | 3.310 | 2.800 | 2.600 | 2.070 | 1.890
3.9 |  | 3.9x1.3 | 3.9x1.3 | 1.3 | 6g | 3.910 | 3.730 | 3.415 | 3.250 | 2.920 | 2.770
3.9 |  | ST3.9x1.3 | ST3.9x1.3 | 1.3 | 6g | 3.910 | 3.730 | 3.415 | 3.250 | 2.920 | 2.770
3.9 |  | 3.9x1.6 | 3.9x1.6 | 1.6 | 6g | 3.910 | 3.730 | 3.300 | 3.135 | 2.690 | 2.540
3.9 |  | 3.9x3.2 | 3.9x3.2 | 3.2 | 6g | 3.910 | 3.690 | 3.180 | 2.980 | 2.450 | 2.270
4.2 |  | 4.2x1.4 | 4.2x1.4 | 1.4 | 6g | 4.220 | 4.040 | 3.660 | 3.495 | 3.100 | 2.950
4.2 |  | ST4.2x1.4 | ST4.2x1.4 | 1.4 | 6g | 4.220 | 4.040 | 3.660 | 3.495 | 3.100 | 2.950
4.2 |  | 4.2x1.6 | 4.2x1.6 | 1.6 | 6g | 4.220 | 4.040 | 3.610 | 3.445 | 3.000 | 2.850
4.2 |  | 4.2x3.2 | 4.2x3.2 | 3.2 | 6g | 4.220 | 4.000 | 3.380 | 3.180 | 2.540 | 2.360
4.8 |  | 4.8x1.6 | 4.8x1.6 | 1.6 | 6g | 4.800 | 4.620 | 4.190 | 4.025 | 3.580 | 3.430
4.8 |  | ST4.8x1.6 | ST4.8x1.6 | 1.6 | 6g | 4.800 | 4.620 | 4.190 | 4.025 | 3.580 | 3.430
4.8 |  | 4.8x1.8 | 4.8x1.8 | 1.8 | 6g | 4.800 | 4.620 | 4.065 | 3.885 | 3.330 | 3.150
4.8 |  | 4.8x3.2 | 4.8x3.2 | 3.2 | 6g | 4.800 | 4.580 | 3.960 | 3.760 | 3.120 | 2.940
5.5 |  | 5.5x1.8 | 5.5x1.8 | 1.8 | 6g | 5.460 | 5.280 | 4.815 | 4.635 | 4.170 | 3.990
5.5 |  | ST5.5x1.8 | ST5.5x1.8 | 1.8 | 6g | 5.460 | 5.280 | 4.815 | 4.635 | 4.170 | 3.990
6.3 |  | 6.3x1.8 | 6.3x1.8 | 1.8 | 6g | 6.250 | 6.030 | 5.565 | 5.365 | 4.880 | 4.700
6.3 |  | ST6.3x1.8 | ST6.3x1.8 | 1.8 | 6g | 6.250 | 6.030 | 5.565 | 5.365 | 4.880 | 4.700
8.0 |  | 8x2.1 | 8x2.1 | 2.1 | 6g | 8.000 | 7.780 | 7.100 | 6.885 | 6.200 | 5.990
8.0 |  | ST8x2.1 | ST8x2.1 | 2.1 | 6g | 8.000 | 7.780 | 7.100 | 6.885 | 6.200 | 5.990
9.5 |  | 9.5x2.1 | 9.5x2.1 | 2.1 | 6g | 9.650 | 9.430 | 8.750 | 8.510 | 7.850 | 7.590
9.5 |  | ST9.5x2.1 | ST9.5x2.1 | 2.1 | 6g | 9.650 | 9.430 | 8.750 | 8.510 | 7.850 | 7.590

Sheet: ISO Pipe Threads
M Q | ISO-Rohrgewinde |  | Sort Order - 9 |  | External |  |  |  |  |  |  | Internal
 |  |  |  |  |  | Major Dia |  | Pitch Dia |  | Minor Dia |  |  | Minor Dia |  | Pitch Dia |  | Major Dia |  | Tap Drill | Thread Depth | Thread Runouts
Size | Size Suffix | Thread Designation | Custom Thread Designation | TPI | Class | Max | Min | Max | Min | Max | Min | Class | Min | Max | Min | Max | Min | Max | Basic
7.723 |  | G7.723x0.907 | G 1/16 | 28 | A | 7.723 | 7.509 | 7.142 | 7.035 | 6.561 |  |  | 6.561 | 6.834 | 7.142 | 7.249 | 7.723 |  | 1.5875 | 15.446 | 4.5000
7.723 |  | G7.723x0.907 | G 1/16 | 28 | B | 7.723 | 7.509 | 7.142 | 6.928 | 6.561
9.728 |  | G9.728x0.907 | G 1/8 | 28 | A | 9.728 | 9.514 | 9.147 | 9.040 | 8.566 |  |  | 8.566 | 8.848 | 9.147 | 9.254 | 9.728 |  | 3.1750 | 19.456 | 4.5000
9.728 |  | G9.728x0.907 | G 1/8 | 28 | B | 9.728 | 9.514 | 9.147 | 8.933 | 8.566
13.157 |  | G13.157x1.337 | G 1/4 | 19 | A | 13.157 | 12.907 | 12.301 | 12.176 | 11.445 |  |  | 11.445 | 11.89 | 12.301 | 12.426 | 13.157 |  | 6.3500 | 26.314 | 6.5000
13.157 |  | G13.157x1.337 | G 1/4 | 19 | B | 13.157 | 12.907 | 12.301 | 12.051 | 11.445
16.662 |  | G16.662x1.337 | G 3/8 | 19 | A | 16.662 | 16.412 | 15.806 | 15.681 | 14.950 |  |  | 14.95 | 15.395 | 15.806 | 15.931 | 16.662 |  | 9.5250 | 33.324 | 6.5000
16.662 |  | G16.662x1.337 | G 3/8 | 19 | B | 16.662 | 16.412 | 15.806 | 15.556 | 14.950
20.955 |  | G20.955x1.814 | G 1/2 | 14 | A | 20.955 | 20.671 | 19.793 | 19.651 | 18.631 |  |  | 18.631 | 19.172 | 19.793 | 19.935 | 20.955 |  | 12.7000 | 41.910 | 8.5000
20.955 |  | G20.955x1.814 | G 1/2 | 14 | B | 20.955 | 20.671 | 19.793 | 19.509 | 18.631
22.911 |  | G22.911x1.814 | G 5/8 | 14 | A | 22.911 | 22.627 | 21.749 | 21.607 | 20.587 |  |  | 20.587 | 21.128 | 21.749 | 21.891 | 22.911 |  |  | 45.822 | 8.5000
22.911 |  | G22.911x1.814 | G 5/8 | 14 | B | 22.911 | 22.627 | 21.749 | 21.465 | 20.587
26.441 |  | G26.441x1.814 | G 3/4 | 14 | A | 26.441 | 26.157 | 25.279 | 25.137 | 24.117 |  |  | 24.117 | 24.658 | 25.279 | 25.421 | 26.441 |  | 15.8750 | 52.882 | 8.5000
26.441 |  | G26.441x1.814 | G 3/4 | 14 | B | 26.441 | 26.157 | 25.279 | 24.995 | 24.117
30.201 |  | G30.201x1.814 | G 7/8 | 14 | A | 30.201 | 29.917 | 29.039 | 28.897 | 27.877 |  |  | 27.877 | 28.418 | 29.039 | 29.181 | 30.201 |  | 22.2250 | 60.402 | 8.5000
30.201 |  | G30.201x1.814 | G 7/8 | 14 | B | 30.201 | 29.917 | 29.039 | 28.755 | 27.877
33.249 |  | G33.249x2.309 | G 1 | 11 | A | 33.249 | 32.889 | 31.770 | 31.590 | 30.291 |  |  | 30.291 | 30.931 | 31.77 | 31.95 | 33.249 |  | 25.4000 | 66.498 | 10.0000
33.249 |  | G33.249x2.309 | G 1 | 11 | B | 33.249 | 32.889 | 31.770 | 31.410 | 30.291
37.897 |  | G37.897x2.309 | G 1 1/8 | 11 | A | 37.897 | 37.537 | 36.418 | 36.238 | 34.939 |  |  | 34.939 | 35.579 | 36.418 | 36.598 | 37.897 |  | 28.5750 | 75.794 | 10.0000
37.897 |  | G37.897x2.309 | G 1 1/8 | 11 | B | 37.897 | 37.537 | 36.418 | 36.058 | 34.939
41.910 |  | G41.91x2.309 | G 1 1/4 | 11 | A | 41.910 | 41.550 | 40.431 | 40.251 | 38.952 |  |  | 38.952 | 39.592 | 40.431 | 40.611 | 41.910 |  | 31.7500 | 83.820 | 10.0000
41.910 |  | G41.91x2.309 | G 1 1/4 | 11 | B | 41.910 | 41.550 | 40.431 | 40.071 | 38.952
47.803 |  | G47.803x2.309 | G 1 1/2 | 11 | A | 47.803 | 47.443 | 46.324 | 46.144 | 44.845 |  |  | 44.845 | 45.485 | 46.324 | 46.504 | 47.803 |  | 38.1000 | 95.606 | 10.0000
47.803 |  | G47.803x2.309 | G 1 1/2 | 11 | B | 47.803 | 47.443 | 46.324 | 45.964 | 44.845
53.746 |  | G53.746x2.309 | G 1 3/4 | 11 | A | 53.746 | 53.386 | 52.267 | 52.087 | 50.788 |  |  | 50.788 | 51.428 | 52.267 | 52.447 | 53.746 |  | 44.4500 | 107.492 | 10.0000
53.746 |  | G53.746x2.309 | G 1 3/4 | 11 | B | 53.746 | 53.386 | 52.267 | 51.907 | 50.788
59.614 |  | G59.614x2.309 | G 2 | 11 | A | 59.614 | 59.254 | 58.135 | 57.955 | 56.656 |  |  | 56.656 | 57.296 | 58.135 | 58.315 | 59.614 |  | 50.8000 | 119.228 | 10.0000
59.614 |  | G59.614x2.309 | G 2 | 11 | B | 59.614 | 59.254 | 58.135 | 57.775 | 56.656
65.710 |  | G65.71x2.309 | G 2 1/4 | 11 | A | 65.710 | 65.276 | 64.231 | 64.014 | 62.752 |  |  | 62.752 | 63.392 | 64.231 | 64.448 | 65.710 |  | 57.1500 | 131.420 | 10.0000
65.710 |  | G65.71x2.309 | G 2 1/4 | 11 | B | 65.710 | 65.276 | 64.231 | 63.797 | 62.752
75.184 |  | G75.184x2.309 | G 2 1/2 | 11 | A | 75.184 | 74.750 | 73.705 | 73.488 | 72.226 |  |  | 72.226 | 72.866 | 73.705 | 73.922 | 75.184 |  |  | 150.368 | 10.0000
75.184 |  | G75.184x2.309 | G 2 1/2 | 11 | B | 75.184 | 74.750 | 73.705 | 73.271 | 72.226
81.534 |  | G81.534x2.309 | G 2 3/4 | 11 | A | 81.534 | 81.100 | 80.055 | 79.838 | 78.576 |  |  | 78.576 | 79.216 | 80.055 | 80.272 | 81.534 |  | 69.8500 | 163.068 | 10.0000
81.534 |  | G81.534x2.309 | G 2 3/4 | 11 | B | 81.534 | 81.100 | 80.055 | 79.621 | 78.576
87.884 |  | G87.884x2.309 | G 3 | 11 | A | 87.884 | 87.450 | 86.405 | 86.188 | 84.926 |  |  | 84.926 | 85.566 | 86.405 | 86.622 | 87.884 |  | 76.2000 | 175.768 | 10.0000
87.884 |  | G87.884x2.309 | G 3 | 11 | B | 87.884 | 87.450 | 86.405 | 85.971 | 84.926
100.330 |  | G100.33x2.309 | G 3 1/2 | 11 | A | 100.330 | 99.896 | 98.851 | 98.634 | 97.372 |  |  | 97.372 | 98.012 | 98.851 | 99.068 | 100.330 |  | 88.9000 | 200.660 | 10.0000
100.330 |  | G100.33x2.309 | G 3 1/2 | 11 | B | 100.330 | 99.896 | 98.851 | 98.417 | 97.372
113.030 |  | G113.03x2.309 | G 4 | 11 | A | 113.030 | 112.596 | 111.551 | 111.334 | 110.072 |  |  | 110.072 | 110.712 | 111.551 | 111.768 | 113.030 |  | 101.6000 | 226.060 | 10.0000
113.030 |  | G113.03x2.309 | G 4 | 11 | B | 113.030 | 112.596 | 111.551 | 111.117 | 110.072
125.730 |  | G125.73x2.309 | G 4 1/2 | 11 | A | 125.730 | 125.296 | 124.251 | 124.034 | 122.772 |  |  | 122.772 | 123.412 | 124.251 | 124.468 | 125.730 |  | 114.3000 | 251.460 | 10.0000
125.730 |  | G125.73x2.309 | G 4 1/2 | 11 | B | 125.730 | 125.296 | 124.251 | 123.817 | 122.772
138.430 |  | G138.43x2.309 | G 5 | 11 | A | 138.430 | 137.996 | 136.951 | 136.734 | 135.472 |  |  | 135.472 | 136.112 | 136.951 | 137.168 | 138.430 |  | 127.0000 | 276.860 | 10.0000
138.430 |  | G138.43x2.309 | G 5 | 11 | B | 138.430 | 137.996 | 136.951 | 136.517 | 135.472
151.130 |  | G151.13x2.309 | G 5 1/2 | 11 | A | 151.130 | 150.696 | 149.651 | 149.434 | 148.172 |  |  | 148.172 | 148.812 | 149.651 | 149.868 | 151.130 |  | 139.7000 | 302.260 | 10.0000
151.130 |  | G151.13x2.309 | G 5 1/2 | 11 | B | 151.130 | 150.696 | 149.651 | 149.217 | 148.172
163.830 |  | G163.83x2.309 | G 6 | 11 | A | 163.830 | 163.396 | 162.351 | 162.134 | 160.872 |  |  | 160.872 | 161.512 | 162.351 | 162.568 | 163.830 |  | 152.4000 | 327.660 | 10.0000
163.830 |  | G163.83x2.309 | G 6 | 11 | B | 163.830 | 163.396 | 162.351 | 161.917 | 160.872

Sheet: JIS Pipe Threads
M Q | JIS-Rohrgewinde |  | Sort Order -12 |  | External |  |  |  |  |  |  | Internal
 |  |  |  |  |  | Major Dia |  | Pitch Dia |  | Minor Dia |  |  | Minor Dia |  | Pitch Dia |  | Major Dia |  | Tap Drill | Thread Depth | Thread Runouts
Size | Size Suffix | Thread Designation | Custom Thread Designation | TPI | Class | Max | Min | Max | Min | Max | Min | Class | Min | Max | Min | Max | Min | Max | Basic |  | Basic
7.723 |  | G7.723x0.907 | G 1/16 | 28 | A | 7.723 | 7.509 | 7.142 | 7.035 | 6.561 |  |  | 6.561 | 6.834 | 7.142 | 7.249 | 7.723 |  | 1.5875 | 15.446 | 4.5000
7.723 |  | G7.723x0.907 | G 1/16 | 28 | B | 7.723 | 7.509 | 7.142 | 6.928 | 6.561
9.728 |  | G9.728x0.907 | G 1/8 | 28 | A | 9.728 | 9.514 | 9.147 | 9.040 | 8.566 |  |  | 8.566 | 8.848 | 9.147 | 9.254 | 9.728 |  | 3.1750 | 19.456 | 4.5000
9.728 |  | G9.728x0.907 | G 1/8 | 28 | B | 9.728 | 9.514 | 9.147 | 8.933 | 8.566
13.157 |  | G13.157x1.337 | G 1/4 | 19 | A | 13.157 | 12.907 | 12.301 | 12.176 | 11.445 |  |  | 11.445 | 11.89 | 12.301 | 12.426 | 13.157 |  | 6.3500 | 26.314 | 6.5000
13.157 |  | G13.157x1.337 | G 1/4 | 19 | B | 13.157 | 12.907 | 12.301 | 12.051 | 11.445
16.662 |  | G16.662x1.337 | G 3/8 | 19 | A | 16.662 | 16.412 | 15.806 | 15.681 | 14.950 |  |  | 14.95 | 15.395 | 15.806 | 15.931 | 16.662 |  | 9.5250 | 33.324 | 6.5000
16.662 |  | G16.662x1.337 | G 3/8 | 19 | B | 16.662 | 16.412 | 15.806 | 15.556 | 14.950
20.955 |  | G20.955x1.814 | G 1/2 | 14 | A | 20.955 | 20.671 | 19.793 | 19.651 | 18.631 |  |  | 18.631 | 19.172 | 19.793 | 19.935 | 20.955 |  | 12.7000 | 41.910 | 8.5000
20.955 |  | G20.955x1.814 | G 1/2 | 14 | B | 20.955 | 20.671 | 19.793 | 19.509 | 18.631
22.911 |  | G22.911x1.814 | G 5/8 | 14 | A | 22.911 | 22.627 | 21.749 | 21.607 | 20.587 |  |  | 20.587 | 21.128 | 21.749 | 21.891 | 22.911 |  |  | 45.822 | 8.5000
22.911 |  | G22.911x1.814 | G 5/8 | 14 | B | 22.911 | 22.627 | 21.749 | 21.465 | 20.587
26.441 |  | G26.441x1.814 | G 3/4 | 14 | A | 26.441 | 26.157 | 25.279 | 25.137 | 24.117 |  |  | 24.117 | 24.658 | 25.279 | 25.421 | 26.441 |  | 15.8750 | 52.882 | 8.5000
26.441 |  | G26.441x1.814 | G 3/4 | 14 | B | 26.441 | 26.157 | 25.279 | 24.995 | 24.117
30.201 |  | G30.201x1.814 | G 7/8 | 14 | A | 30.201 | 29.917 | 29.039 | 28.897 | 27.877 |  |  | 27.877 | 28.418 | 29.039 | 29.181 | 30.201 |  | 22.2250 | 60.402 | 8.8000
30.201 |  | G30.201x1.814 | G 7/8 | 14 | B | 30.201 | 29.917 | 29.039 | 28.755 | 27.877
33.249 |  | G33.249x2.309 | G 1 | 11 | A | 33.249 | 32.889 | 31.770 | 31.590 | 30.291 |  |  | 30.291 | 30.931 | 31.77 | 31.95 | 33.249 |  | 25.4000 | 66.498 | 10.0000
33.249 |  | G33.249x2.309 | G 1 | 11 | B | 33.249 | 32.889 | 31.770 | 31.410 | 30.291
37.897 |  | G37.897x2.309 | G 1 1/8 | 11 | A | 37.897 | 37.537 | 36.418 | 36.238 | 34.939 |  |  | 34.939 | 35.579 | 36.418 | 36.598 | 37.897 |  | 28.5750 | 75.794 | 10.0000
37.897 |  | G37.897x2.309 | G 1 1/8 | 11 | B | 37.897 | 37.537 | 36.418 | 36.058 | 34.939
41.910 |  | G41.91x2.309 | G 1 1/4 | 11 | A | 41.910 | 41.550 | 40.431 | 40.251 | 38.952 |  |  | 38.952 | 39.592 | 40.431 | 40.611 | 41.910 |  | 31.7500 | 83.820 | 10.0000
41.910 |  | G41.91x2.309 | G 1 1/4 | 11 | B | 41.910 | 41.550 | 40.431 | 40.071 | 38.952
47.803 |  | G47.803x2.309 | G 1 1/2 | 11 | A | 47.803 | 47.443 | 46.324 | 46.144 | 44.845 |  |  | 44.845 | 45.485 | 46.324 | 46.504 | 47.803 |  | 38.1000 | 95.606 | 10.0000
47.803 |  | G47.803x2.309 | G 1 1/2 | 11 | B | 47.803 | 47.443 | 46.324 | 45.964 | 44.845
53.746 |  | G53.746x2.309 | G 1 3/4 | 11 | A | 53.746 | 53.386 | 52.267 | 52.087 | 50.788 |  |  | 50.788 | 51.428 | 52.267 | 52.447 | 53.746 |  | 44.4500 | 107.492 | 10.0000
53.746 |  | G53.746x2.309 | G 1 3/4 | 11 | B | 53.746 | 53.386 | 52.267 | 51.907 | 50.788
59.614 |  | G59.614x2.309 | G 2 | 11 | A | 59.614 | 59.254 | 58.135 | 57.955 | 56.656 |  |  | 56.656 | 57.296 | 58.135 | 58.315 | 59.614 |  | 50.8000 | 119.228 | 10.0000
59.614 |  | G59.614x2.309 | G 2 | 11 | B | 59.614 | 59.254 | 58.135 | 57.775 | 56.656
65.710 |  | G65.71x2.309 | G 2 1/4 | 11 | A | 65.710 | 65.276 | 64.231 | 64.014 | 62.752 |  |  | 62.752 | 63.392 | 64.231 | 64.448 | 65.710 |  | 57.1500 | 131.420 | 10.0000
65.710 |  | G65.71x2.309 | G 2 1/4 | 11 | B | 65.710 | 65.276 | 64.231 | 63.797 | 62.752
75.184 |  | G75.184x2.309 | G 2 1/2 | 11 | A | 75.184 | 74.750 | 73.705 | 73.488 | 72.226 |  |  | 72.226 | 72.866 | 73.705 | 73.922 | 75.184 |  |  | 150.368 | 10.0000
75.184 |  | G75.184x2.309 | G 2 1/2 | 11 | B | 75.184 | 74.750 | 73.705 | 73.271 | 72.226
81.534 |  | G81.534x2.309 | G 2 3/4 | 11 | A | 81.534 | 81.100 | 80.055 | 79.838 | 78.576 |  |  | 78.576 | 79.216 | 80.055 | 80.272 | 81.534 |  | 69.8500 | 163.068 | 10.0000
81.534 |  | G81.534x2.309 | G 2 3/4 | 11 | B | 81.534 | 81.100 | 80.055 | 79.621 | 78.576
87.884 |  | G87.884x2.309 | G 3 | 11 | A | 87.884 | 87.450 | 86.405 | 86.188 | 84.926 |  |  | 84.926 | 85.566 | 86.405 | 86.622 | 87.884 |  | 76.2000 | 175.768 | 10.0000
87.884 |  | G87.884x2.309 | G 3 | 11 | B | 87.884 | 87.450 | 86.405 | 85.971 | 84.926
100.330 |  | G100.33x2.309 | G 3 1/2 | 11 | A | 100.330 | 99.896 | 98.851 | 98.634 | 97.372 |  |  | 97.372 | 98.012 | 98.851 | 99.068 | 100.330 |  | 88.9000 | 200.660 | 10.0000
100.330 |  | G100.33x2.309 | G 3 1/2 | 11 | B | 100.330 | 99.896 | 98.851 | 98.417 | 97.372
113.030 |  | G113.03x2.309 | G 4 | 11 | A | 113.030 | 112.596 | 111.551 | 111.334 | 110.072 |  |  | 110.072 | 110.712 | 111.551 | 111.768 | 113.030 |  | 101.6000 | 226.060 | 10.0000
113.030 |  | G113.03x2.309 | G 4 | 11 | B | 113.030 | 112.596 | 111.551 | 111.117 | 110.072
125.730 |  | G125.73x2.309 | G 4 1/2 | 11 | A | 125.730 | 125.296 | 124.251 | 124.034 | 122.772 |  |  | 122.772 | 123.412 | 124.251 | 124.468 | 125.730 |  | 114.3000 | 251.460 | 10.0000
125.730 |  | G125.73x2.309 | G 4 1/2 | 11 | B | 125.730 | 125.296 | 124.251 | 123.817 | 122.772
138.430 |  | G138.43x2.309 | G 5 | 11 | A | 138.430 | 137.996 | 136.951 | 136.734 | 135.472 |  |  | 135.472 | 136.112 | 136.951 | 137.168 | 138.430 |  | 127.0000 | 276.860 | 10.0000
138.430 |  | G138.43x2.309 | G 5 | 11 | B | 138.430 | 137.996 | 136.951 | 136.517 | 135.472
151.130 |  | G151.13x2.309 | G 5 1/2 | 11 | A | 151.130 | 150.696 | 149.651 | 149.434 | 148.172 |  |  | 148.172 | 148.812 | 149.651 | 149.868 | 151.130 |  | 139.7000 | 302.260 | 10.0000
151.130 |  | G151.13x2.309 | G 5 1/2 | 11 | B | 151.130 | 150.696 | 149.651 | 149.217 | 148.172
163.830 |  | G163.83x2.309 | G 6 | 11 | A | 163.830 | 163.396 | 162.351 | 162.134 | 160.872 |  |  | 160.872 | 161.512 | 162.351 | 162.568 | 163.830 |  | 152.4000 | 327.660 | 10.0000
163.830 |  | G163.83x2.309 | G 6 | 11 | B | 163.830 | 163.396 | 162.351 | 161.917 | 160.872

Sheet: DIN Pipe Threads
M Q | DIN-Rohrgewinde |  | Sort Order - 18 |  | External |  |  |  |  |  |  | Internal
 |  |  |  |  |  | Major Dia |  | Pitch Dia |  | Minor Dia |  |  | Minor Dia |  | Pitch Dia |  | Major Dia |  | Tap Drill | Thread Depth | Thread Runouts
Size | Size Suffix | Thread Designation | Custom Thread Designation | TPI | Class | Max | Min | Max | Min | Max | Min | Class | Min | Max | Min | Max | Min | Max | Basic
7.723 |  | G7.723x0.907 | G 1/16 | 28 | A | 7.723 | 7.509 | 7.142 | 7.035 | 6.561 |  |  | 6.561 | 6.834 | 7.142 | 7.249 | 7.723 |  | 1.5875 | 15.446 | 4.5000
7.723 |  | G7.723x0.907 | G 1/16 | 28 | B | 7.723 | 7.509 | 7.142 | 6.928 | 6.561
9.728 |  | G9.728x0.907 | G 1/8 | 28 | A | 9.728 | 9.514 | 9.147 | 9.040 | 8.566 |  |  | 8.566 | 8.848 | 9.147 | 9.254 | 9.728 |  | 3.1750 | 19.456 | 4.5000
9.728 |  | G9.728x0.907 | G 1/8 | 28 | B | 9.728 | 9.514 | 9.147 | 8.933 | 8.566
13.157 |  | G13.157x1.337 | G 1/4 | 19 | A | 13.157 | 12.907 | 12.301 | 12.176 | 11.445 |  |  | 11.445 | 11.89 | 12.301 | 12.426 | 13.157 |  | 6.3500 | 26.314 | 6.5000
13.157 |  | G13.157x1.337 | G 1/4 | 19 | B | 13.157 | 12.907 | 12.301 | 12.051 | 11.445
16.662 |  | G16.662x1.337 | G 3/8 | 19 | A | 16.662 | 16.412 | 15.806 | 15.681 | 14.950 |  |  | 14.95 | 15.395 | 15.806 | 15.931 | 16.662 |  | 9.5250 | 33.324 | 6.5000
16.662 |  | G16.662x1.337 | G 3/8 | 19 | B | 16.662 | 16.412 | 15.806 | 15.556 | 14.950
20.955 |  | G20.955x1.814 | G 1/2 | 14 | A | 20.955 | 20.671 | 19.793 | 19.651 | 18.631 |  |  | 18.631 | 19.172 | 19.793 | 19.935 | 20.955 |  | 12.7000 | 41.910 | 8.5000
20.955 |  | G20.955x1.814 | G 1/2 | 14 | B | 20.955 | 20.671 | 19.793 | 19.509 | 18.631
22.911 |  | G22.911x1.814 | G 5/8 | 14 | A | 22.911 | 22.627 | 21.749 | 21.607 | 20.587 |  |  | 20.587 | 21.128 | 21.749 | 21.891 | 22.911 |  |  | 45.822 | 8.5000
22.911 |  | G22.911x1.814 | G 5/8 | 14 | B | 22.911 | 22.627 | 21.749 | 21.465 | 20.587
26.441 |  | G26.441x1.814 | G 3/4 | 14 | A | 26.441 | 26.157 | 25.279 | 25.137 | 24.117 |  |  | 24.117 | 24.658 | 25.279 | 25.421 | 26.441 |  | 15.8750 | 52.882 | 8.5000
26.441 |  | G26.441x1.814 | G 3/4 | 14 | B | 26.441 | 26.157 | 25.279 | 24.995 | 24.117
30.201 |  | G30.201x1.814 | G 7/8 | 14 | A | 30.201 | 29.917 | 29.039 | 28.897 | 27.877 |  |  | 27.877 | 28.418 | 29.039 | 29.181 | 30.201 |  | 22.2250 | 60.402 | 8.5000
30.201 |  | G30.201x1.814 | G 7/8 | 14 | B | 30.201 | 29.917 | 29.039 | 28.755 | 27.877
33.249 |  | G33.249x2.309 | G 1 | 11 | A | 33.249 | 32.889 | 31.770 | 31.590 | 30.291 |  |  | 30.291 | 30.931 | 31.77 | 31.95 | 33.249 |  | 25.4000 | 66.498 | 10.5000
33.249 |  | G33.249x2.309 | G 1 | 11 | B | 33.249 | 32.889 | 31.770 | 31.410 | 30.291
37.897 |  | G37.897x2.309 | G 1 1/8 | 11 | A | 37.897 | 37.537 | 36.418 | 36.238 | 34.939 |  |  | 34.939 | 35.579 | 36.418 | 36.598 | 37.897 |  | 28.5750 | 75.794 | 10.5000
37.897 |  | G37.897x2.309 | G 1 1/8 | 11 | B | 37.897 | 37.537 | 36.418 | 36.058 | 34.939
41.910 |  | G41.91x2.309 | G 1 1/4 | 11 | A | 41.910 | 41.550 | 40.431 | 40.251 | 38.952 |  |  | 38.952 | 39.592 | 40.431 | 40.611 | 41.910 |  | 31.7500 | 83.820 | 10.5000
41.910 |  | G41.91x2.309 | G 1 1/4 | 11 | B | 41.910 | 41.550 | 40.431 | 40.071 | 38.952
47.803 |  | G47.803x2.309 | G 1 1/2 | 11 | A | 47.803 | 47.443 | 46.324 | 46.144 | 44.845 |  |  | 44.845 | 45.485 | 46.324 | 46.504 | 47.803 |  | 38.1000 | 95.606 | 10.5000
47.803 |  | G47.803x2.309 | G 1 1/2 | 11 | B | 47.803 | 47.443 | 46.324 | 45.964 | 44.845
53.746 |  | G53.746x2.309 | G 1 3/4 | 11 | A | 53.746 | 53.386 | 52.267 | 52.087 | 50.788 |  |  | 50.788 | 51.428 | 52.267 | 52.447 | 53.746 |  | 44.4500 | 107.492 | 10.5000
53.746 |  | G53.746x2.309 | G 1 3/4 | 11 | B | 53.746 | 53.386 | 52.267 | 51.907 | 50.788
59.614 |  | G59.614x2.309 | G 2 | 11 | A | 59.614 | 59.254 | 58.135 | 57.955 | 56.656 |  |  | 56.656 | 57.296 | 58.135 | 58.315 | 59.614 |  | 50.8000 | 119.228 | 10.5000
59.614 |  | G59.614x2.309 | G 2 | 11 | B | 59.614 | 59.254 | 58.135 | 57.775 | 56.656
65.710 |  | G65.71x2.309 | G 2 1/4 | 11 | A | 65.710 | 65.276 | 64.231 | 64.014 | 62.752 |  |  | 62.752 | 63.392 | 64.231 | 64.448 | 65.710 |  | 57.1500 | 131.420 | 10.5000
65.710 |  | G65.71x2.309 | G 2 1/4 | 11 | B | 65.710 | 65.276 | 64.231 | 63.797 | 62.752
75.184 |  | G75.184x2.309 | G 2 1/2 | 11 | A | 75.184 | 74.750 | 73.705 | 73.488 | 72.226 |  |  | 72.226 | 72.866 | 73.705 | 73.922 | 75.184 |  |  | 150.368 | 10.5000
75.184 |  | G75.184x2.309 | G 2 1/2 | 11 | B | 75.184 | 74.750 | 73.705 | 73.271 | 72.226
81.534 |  | G81.534x2.309 | G 2 3/4 | 11 | A | 81.534 | 81.100 | 80.055 | 79.838 | 78.576 |  |  | 78.576 | 79.216 | 80.055 | 80.272 | 81.534 |  | 69.8500 | 163.068 | 10.5000
81.534 |  | G81.534x2.309 | G 2 3/4 | 11 | B | 81.534 | 81.100 | 80.055 | 79.621 | 78.576
87.884 |  | G87.884x2.309 | G 3 | 11 | A | 87.884 | 87.450 | 86.405 | 86.188 | 84.926 |  |  | 84.926 | 85.566 | 86.405 | 86.622 | 87.884 |  | 76.2000 | 175.768 | 10.5000
87.884 |  | G87.884x2.309 | G 3 | 11 | B | 87.884 | 87.450 | 86.405 | 85.971 | 84.926
100.330 |  | G100.33x2.309 | G 3 1/2 | 11 | A | 100.330 | 99.896 | 98.851 | 98.634 | 97.372 |  |  | 97.372 | 98.012 | 98.851 | 99.068 | 100.330 |  | 88.9000 | 200.660 | 10.5000
100.330 |  | G100.33x2.309 | G 3 1/2 | 11 | B | 100.330 | 99.896 | 98.851 | 98.417 | 97.372
113.030 |  | G113.03x2.309 | G 4 | 11 | A | 113.030 | 112.596 | 111.551 | 111.334 | 110.072 |  |  | 110.072 | 110.712 | 111.551 | 111.768 | 113.030 |  | 101.6000 | 226.060 | 10.5000
113.030 |  | G113.03x2.309 | G 4 | 11 | B | 113.030 | 112.596 | 111.551 | 111.117 | 110.072
125.730 |  | G125.73x2.309 | G 4 1/2 | 11 | A | 125.730 | 125.296 | 124.251 | 124.034 | 122.772 |  |  | 122.772 | 123.412 | 124.251 | 124.468 | 125.730 |  | 114.3000 | 251.460 | 10.5000
125.730 |  | G125.73x2.309 | G 4 1/2 | 11 | B | 125.730 | 125.296 | 124.251 | 123.817 | 122.772
138.430 |  | G138.43x2.309 | G 5 | 11 | A | 138.430 | 137.996 | 136.951 | 136.734 | 135.472 |  |  | 135.472 | 136.112 | 136.951 | 137.168 | 138.430 |  | 127.0000 | 276.860 | 10.5000
138.430 |  | G138.43x2.309 | G 5 | 11 | B | 138.430 | 137.996 | 136.951 | 136.517 | 135.472
151.130 |  | G151.13x2.309 | G 5 1/2 | 11 | A | 151.130 | 150.696 | 149.651 | 149.434 | 148.172 |  |  | 148.172 | 148.812 | 149.651 | 149.868 | 151.130 |  | 139.7000 | 302.260 | 10.5000
151.130 |  | G151.13x2.309 | G 5 1/2 | 11 | B | 151.130 | 150.696 | 149.651 | 149.217 | 148.172
163.830 |  | G163.83x2.309 | G 6 | 11 | A | 163.830 | 163.396 | 162.351 | 162.134 | 160.872 |  |  | 160.872 | 161.512 | 162.351 | 162.568 | 163.830 |  | 152.4000 | 327.660 | 10.5000
163.830 |  | G163.83x2.309 | G 6 | 11 | B | 163.830 | 163.396 | 162.351 | 161.917 | 160.872

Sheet: BSP Pipe Threads
M Q | BSP-Rohrgewinde |  | Sort Order - 19 |  | External |  |  |  |  |  |  | Internal
 |  |  |  |  |  | Major Dia |  | Pitch Dia |  | Minor Dia |  |  | Minor Dia |  | Pitch Dia |  | Major Dia |  | Tap Drill | Thread Depth | Thread Runouts
Size | Size Suffix | Thread Designation | Custom Thread Designation | TPI | Class | Max | Min | Max | Min | Max | Min | Class | Min | Max | Min | Max | Min | Max | Basic |  | Basic
1/16 |  | G 1/16-28 | G 1/16-28 | 28 | A | 7.723 | 7.509 | 7.142 | 7.035 | 6.561 |  |  | 6.561 | 6.834 | 7.142 | 7.249 | 7.723 |  | 6.6000 | 15.4460 | 4.5000
1/16 |  | G 1/16-28 | G 1/16-28 | 28 | B | 7.723 | 7.509 | 7.142 | 7.035 | 6.561
1/8 |  | G 1/8-28 | G 1/8-28 | 28 | A | 9.728 | 9.514 | 9.147 | 9.040 | 8.566 |  |  | 8.566 | 8.848 | 9.147 | 9.254 | 9.728 |  | 8.7300 | 19.4560 | 4.5000
1/8 |  | G 1/8-28 | G 1/8-28 | 28 | B | 9.728 | 9.514 | 9.147 | 9.040 | 8.566
1/4 |  | G 1/4-19 | G 1/4-19 | 19 | A | 13.157 | 12.907 | 12.301 | 12.176 | 11.445 |  |  | 11.445 | 11.89 | 12.301 | 12.426 | 13.157 |  | 11.8000 | 26.3140 | 6.5000
1/4 |  | G 1/4-19 | G 1/4-19 | 19 | B | 13.157 | 12.907 | 12.301 | 12.176 | 11.445
3/8 |  | G 3/8-19 | G 3/8-19 | 19 | A | 16.662 | 16.412 | 15.806 | 15.681 | 14.950 |  |  | 14.95 | 15.395 | 15.806 | 15.931 | 16.662 |  | 15.2500 | 33.3240 | 6.5000
3/8 |  | G 3/8-19 | G 3/8-19 | 19 | B | 16.662 | 16.412 | 15.806 | 15.681 | 14.950
1/2 |  | G 1/2-14 | G 1/2-14 | 14 | A | 20.955 | 20.671 | 19.793 | 19.651 | 18.631 |  |  | 18.631 | 19.172 | 19.793 | 19.935 | 20.955 |  | 19.0500 | 41.9100 | 8.5000
1/2 |  | G 1/2-14 | G 1/2-14 | 14 | B | 20.955 | 20.671 | 19.793 | 19.651 | 18.631
5/8 |  | G 5/8-14 | G 5/8-14 | 14 | A | 22.911 | 22.627 | 21.749 | 21.607 | 20.587 |  |  | 20.587 | 21.128 | 21.749 | 21.891 | 22.911 |  | 21.0000 | 45.8220 | 8.5000
5/8 |  | G 5/8-14 | G 5/8-14 | 14 | B | 22.911 | 22.627 | 21.749 | 21.607 | 20.587
3/4 |  | G 3/4-14 | G 3/4-14 | 14 | A | 26.441 | 26.157 | 25.279 | 25.137 | 24.117 |  |  | 24.117 | 24.658 | 25.279 | 25.421 | 26.441 |  | 24.5000 | 52.8820 | 8.5000
3/4 |  | G 3/4-14 | G 3/4-14 | 14 | B | 26.441 | 26.157 | 25.279 | 25.137 | 24.117
7/8 |  | G 7/8-14 | G 7/8-14 | 14 | A | 30.201 | 29.917 | 29.039 | 28.897 | 27.877 |  |  | 27.877 | 28.418 | 29.039 | 29.181 | 30.201 |  | 28.2500 | 60.4020 | 8.5000
7/8 |  | G 7/8-14 | G 7/8-14 | 14 | B | 30.201 | 29.917 | 29.039 | 28.897 | 27.877
1 |  | G 1-11 | G 1-11 | 11 | A | 33.249 | 32.889 | 31.770 | 31.590 | 30.291 |  |  | 30.291 | 30.931 | 31.77 | 31.95 | 33.249 |  | 30.7500 | 66.4980 | 10.0000
1 |  | G 1-11 | G 1-11 | 11 | B | 33.249 | 32.889 | 31.770 | 31.590 | 30.291
1 1/4 |  | G 1 1/4-11 | G 1 1/4-11 | 11 | A | 41.910 | 41.550 | 40.431 | 40.251 | 38.952 |  |  | 38.952 | 39.592 | 40.431 | 40.611 | 41.910 |  | 39.5000 | 83.8200 | 10.0000
1 1/4 |  | G 1 1/4-11 | G 1 1/4-11 | 11 | B | 41.910 | 41.550 | 40.431 | 40.251 | 38.952
1 1/2 |  | G 1 1/2-11 | G 1 1/2-11 | 11 | A | 47.803 | 47.443 | 46.324 | 46.144 | 44.845 |  |  | 44.845 | 45.485 | 46.324 | 46.504 | 47.803 |  | 45.5000 | 95.6060 | 10.0000
1 1/2 |  | G 1 1/2-11 | G 1 1/2-11 | 11 | B | 47.803 | 47.443 | 46.324 | 46.144 | 44.845
1 3/4 |  | G 1 3/4-11 | G 1 3/4-11 | 11 | A | 53.746 | 53.386 | 52.267 | 52.087 | 50.788 |  |  | 50.788 | 51.428 | 52.267 | 52.447 | 53.746 |  | 51.0000 | 107.4920 | 10.0000
1 3/4 |  | G 1 3/4-11 | G 1 3/4-11 | 11 | B | 53.746 | 53.386 | 52.267 | 52.087 | 50.788
2 |  | G 2-11 | G 2-11 | 11 | A | 59.614 | 59.254 | 58.135 | 57.955 | 56.656 |  |  | 56.656 | 57.296 | 58.135 | 58.315 | 59.614 |  | 57.0000 | 119.2280 | 10.0000
2 |  | G 2-11 | G 2-11 | 11 | B | 59.614 | 59.254 | 58.135 | 57.955 | 56.656
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

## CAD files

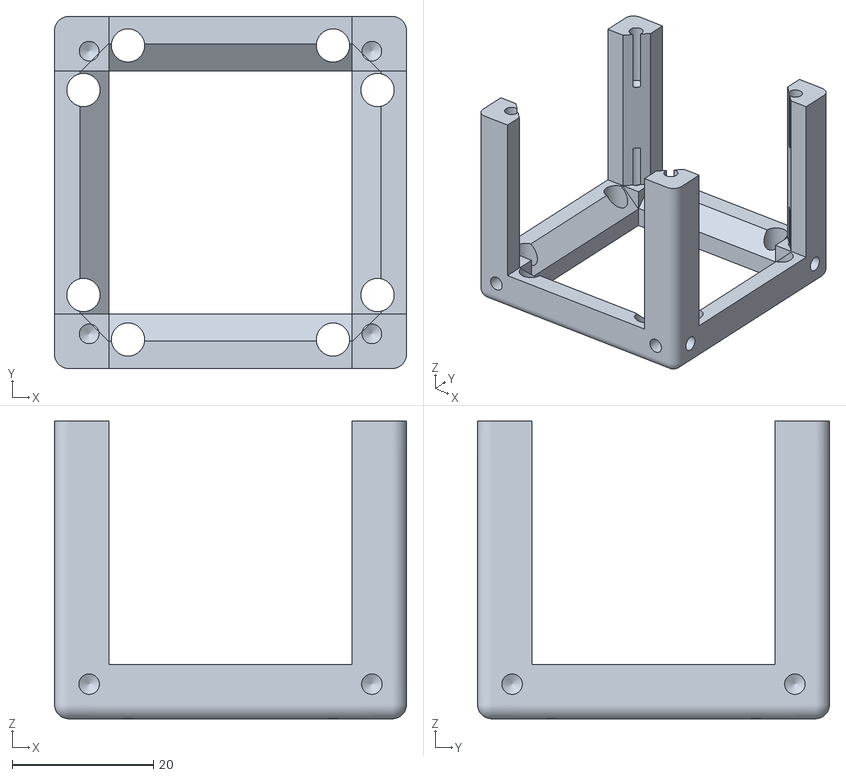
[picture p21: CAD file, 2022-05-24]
STL/basecube_v3/UC2_v3_10_Cube_1x1_v3.stl
49.8 x 49.8 x 42.1

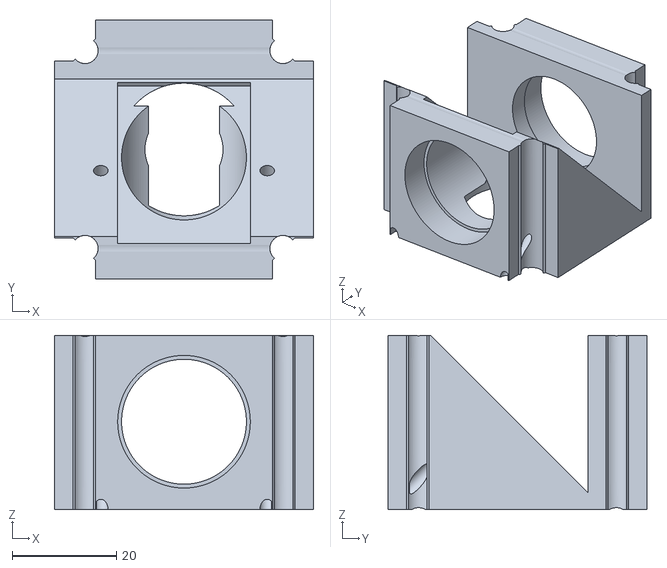
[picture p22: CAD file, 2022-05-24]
STL/beamsplitter/20_Cube_Insert_Beamsplittercube_Base_25x35_v3.stl
49.8 x 49.8 x 33.5

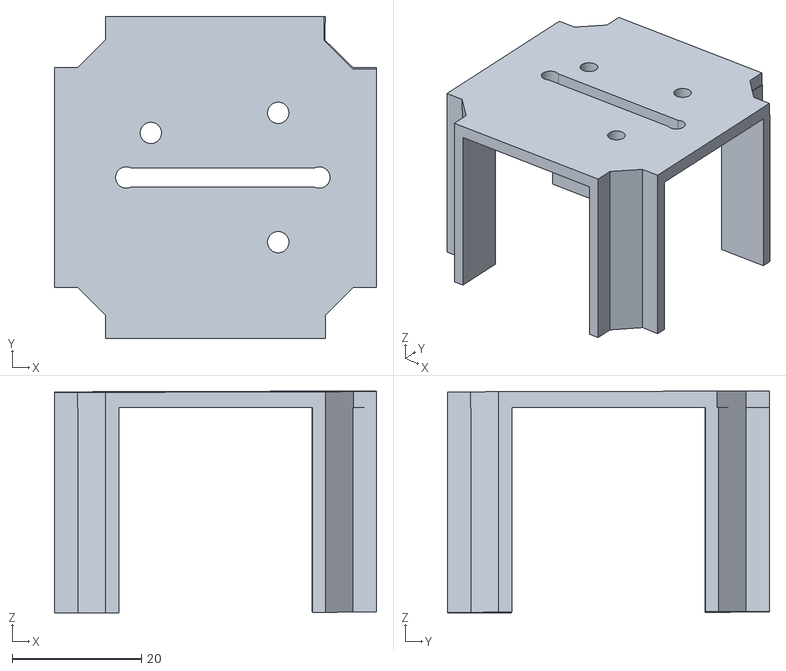
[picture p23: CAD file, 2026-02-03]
STL/camera_holder/UC2-Print_all_STLs_once/1_20_Cube_insert_AlliedVision_Alvium_v3.stl
49.8 x 49.8 x 34.3

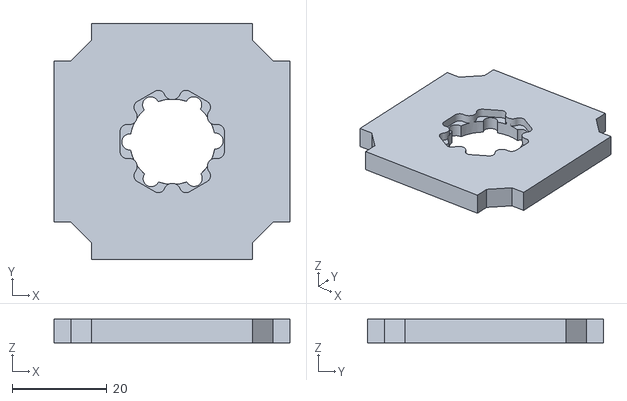
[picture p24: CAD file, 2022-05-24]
STL/LED_holder/LED_holder_metal.stl
49.8 x 49.8 x 5.00

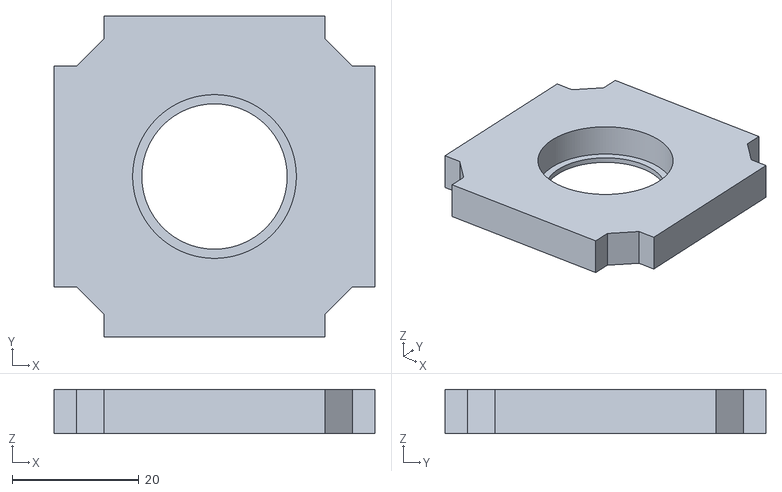
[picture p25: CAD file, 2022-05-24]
STL/lens_holder/insert_lens_1inch_3.stl
50.6 x 50.6 x 7.00

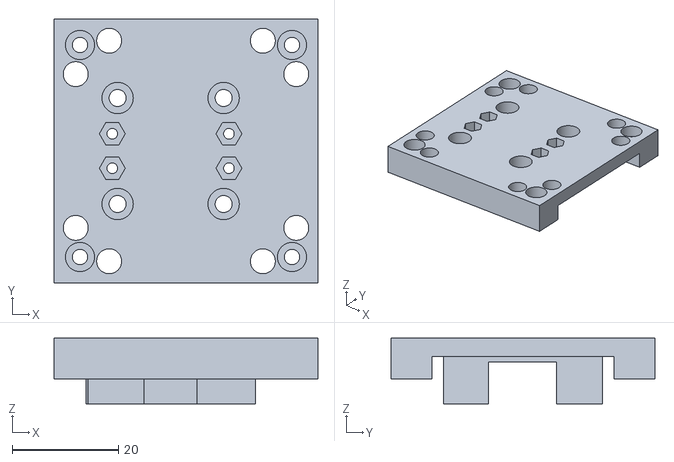
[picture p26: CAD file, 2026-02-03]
STL/motor_holder/StructureTop.stl
49.8 x 49.8 x 12.4

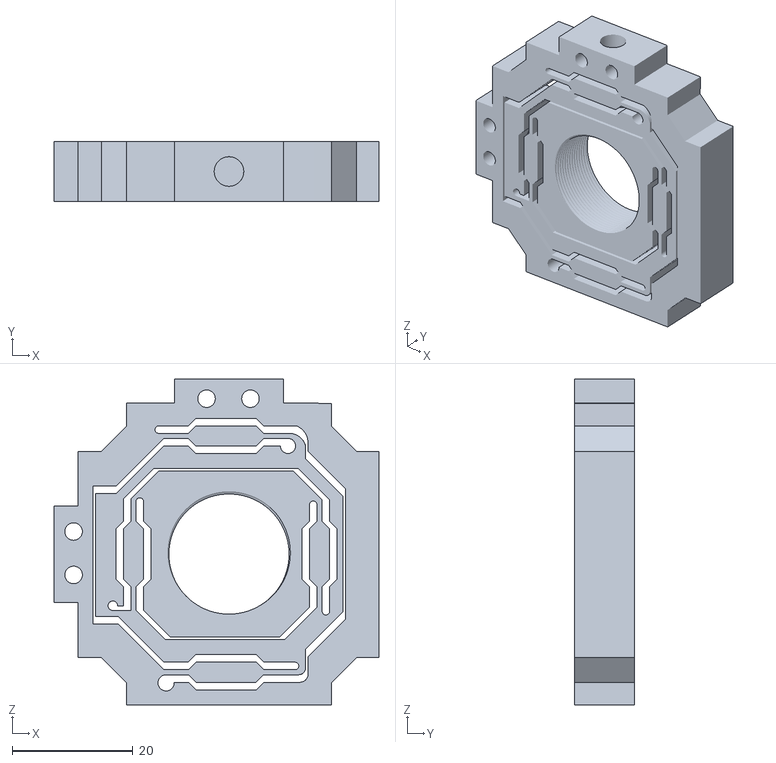
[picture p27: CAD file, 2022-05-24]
STL/objective_holder/Application_OpenFiberCoupling_20_Cube_Inser_Flexuremanipulator_v3.stl
53.8 x 10.0 x 54.0

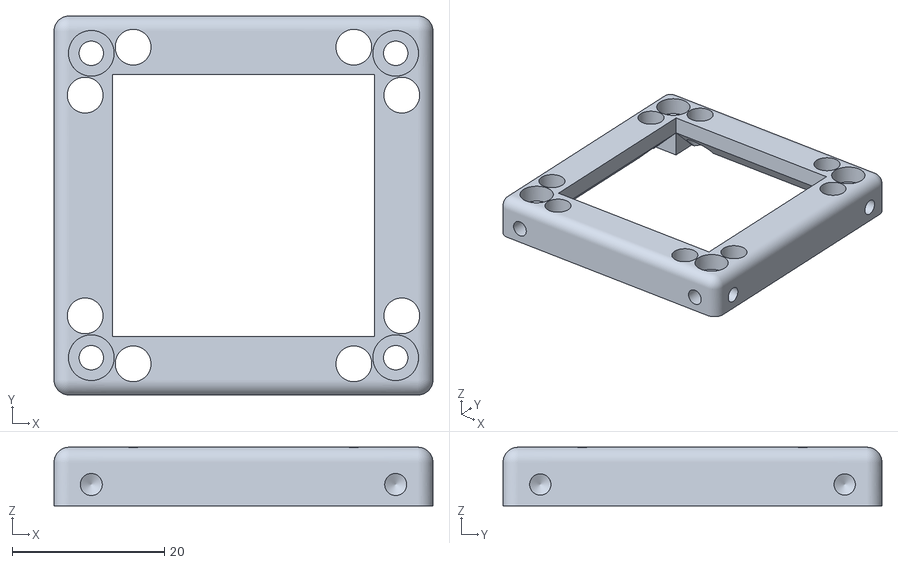
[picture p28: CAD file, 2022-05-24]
STL/basecube_v3/UC2_v3_10_Lid_1x1_v3.stl
49.8 x 49.8 x 7.70

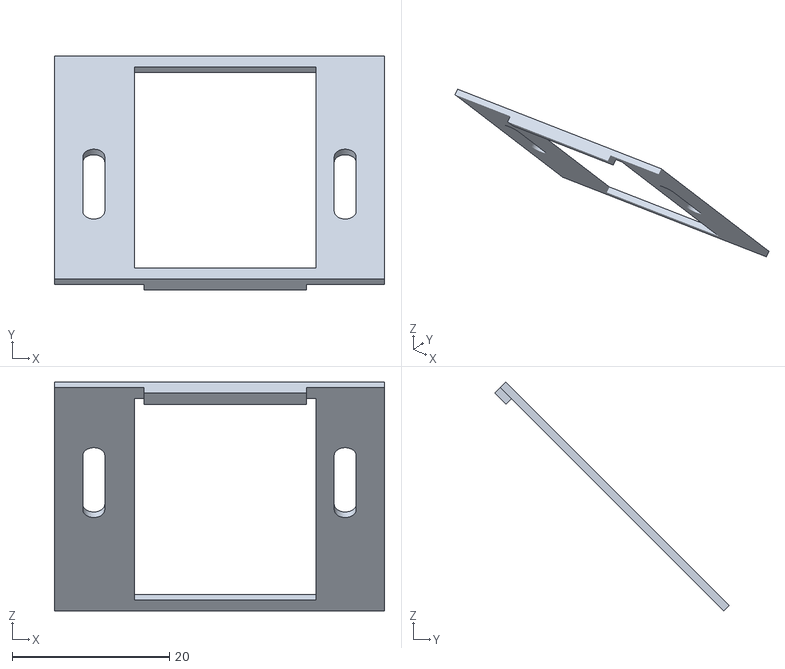
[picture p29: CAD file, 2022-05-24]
STL/beamsplitter/beamsplitter_clamp_edited.stl
42.0 x 29.8 x 29.1

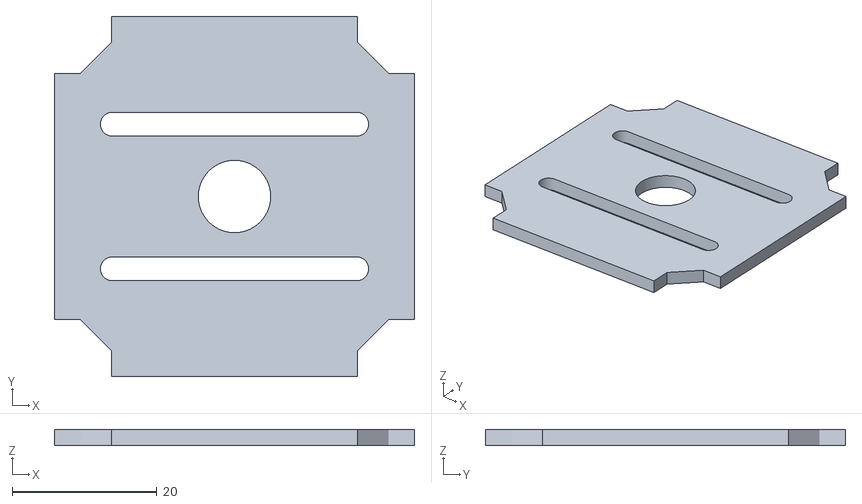
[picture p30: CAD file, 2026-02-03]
STL/camera_holder/UC2-Print_all_STLs_once/0_20_Cube_insert_AlliedVision_Alvium_adjustable_v3.stl
49.8 x 49.8 x 2.25

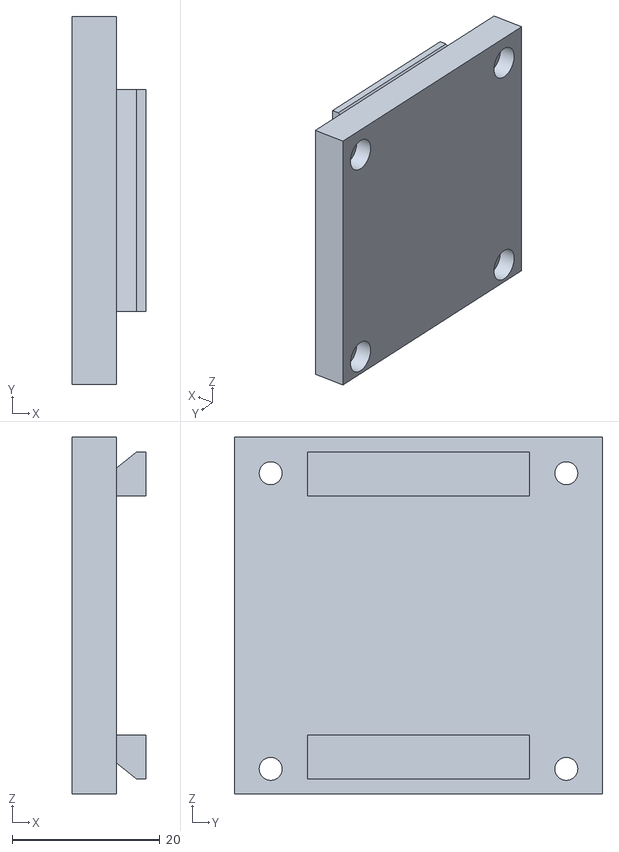
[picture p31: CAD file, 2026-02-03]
STL/motor_holder/SampleHolder.stl
10.0 x 49.8 x 48.3

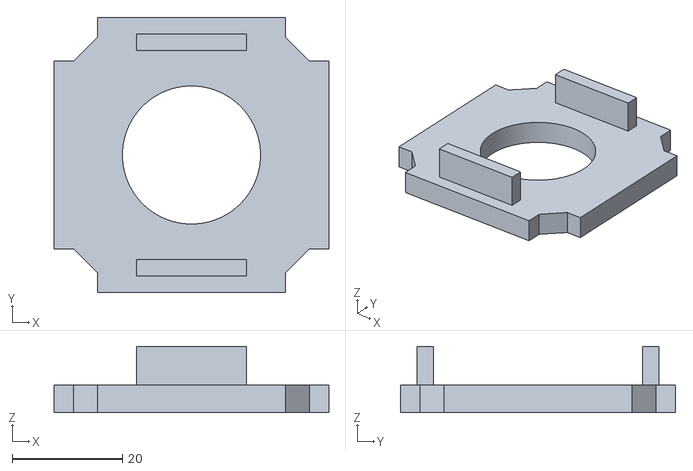
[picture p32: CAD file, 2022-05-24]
STL/objective_holder/20_Cube_insert_Sample_holder_v3.stl
49.8 x 49.8 x 12.0

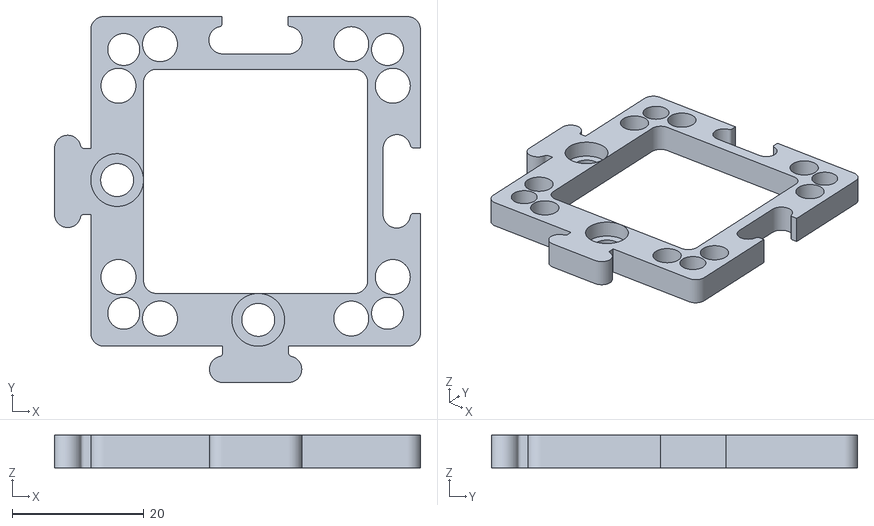
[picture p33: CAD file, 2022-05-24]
STL/basecube_v3/UC2_v3_10_Base_puzzle_v3.stl
55.5 x 55.5 x 5.00

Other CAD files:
CAD/Templates/English/ANSI (in).dwg
CAD/Templates/Metric/GOST.dwg
CAD/Templates/Standard.dwg
CAD/Templates/Metric/DIN.dwg
CAD/Templates/Metric/JIS.dwg
CAD/motor_holder_openscad/FocusMicroscope.scad
CAD/motor_holder_openscad/LinearSlider.scad
CAD/motor_holder_openscad/materials.scad
CAD/motor_holder_openscad/screws.scad
CAD/00_Alvium_Step_USB90_S-Mount_ClosedHousing_2019-Mar-28.ipt
CAD/00_BallMagnets_5mm_single.ipt
CAD/00_Chroma_Dichroic_25x,3x1.ipt
CAD/00_Comar_Filter_25Dia.ipt
CAD/00_Laser_532nm_200mw.ipt
CAD/00_MGN12H, LINEAR GUIDE BLOCK.ipt
CAD/00_Microscope_Objective.ipt
CAD/00_Motorcoupling_5mm_M3.ipt
CAD/00_NEMA11.ipt
CAD/00_SMLM_chamber.ipt
CAD/00_Stepper_Motor_28BYJ-48.ipt
CAD/00_Thorlabs_PF10-03-P01-Step.ipt
CAD/00_XY_stage-CHUO_SEIKI_LD-647-R1-Bottom.ipt
CAD/00_XY_stage-CHUO_SEIKI_LD-647-R1-Middle.ipt
CAD/00_XY_stage-CHUO_SEIKI_LD-647-R1-Top.ipt
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

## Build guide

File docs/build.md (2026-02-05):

---
layout: default
title: Build instructions
nav_order: 3
---

# Light sources
### Soldering

 Solder LEDs to star PCB. This first step is the hardest of the tutorial. First tin-coat the electrodes of the LED. Make sure the electrodes are not gated by the tin. Let the PCB star warm to 200&deg;C on a heating plate. Then connect the LED to the PCB star, apply pressure. Take the mounted LED from the plate and let it cool down. Solder the electric wires to PCB.

<p align="center">
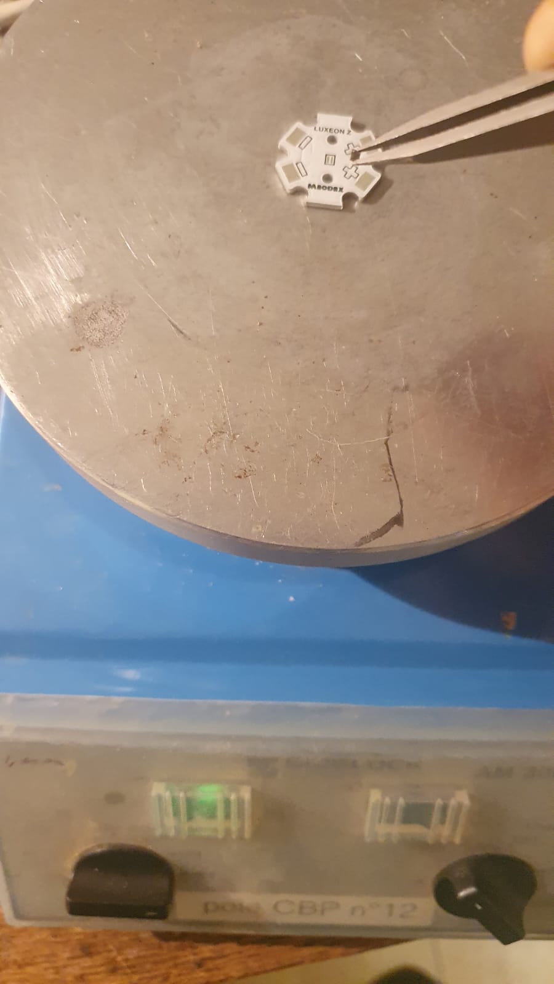
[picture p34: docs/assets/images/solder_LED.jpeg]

</p>

### Control
If you do not yet have access to LED drivers(example: [1](https://www.thorlabs.com/newgrouppage9.cfm?objectgroup_id=2616), [2](https://www.thorlabs.us/thorProduct.cfm?partNumber=DC4104).), the first option is to build a minimal LED controller circuit. You will need the RECOM DC/DC converter, a potentiometer and electric wires. Use a regulated power supply to power the RECOM and another for the potentiometer. 

The second option is to build an LED driver. We are currently develping a board allowing to build the LED controller. You can find the first design files [HERE - v1](https://github.com/Julie-Mauguit/CSL-light-hardware) and the second version [HERE - V2](https://github.com/corset-damien/CSL-light-hardware). Disclaimer: This work is not stable yet (beta). 

>You can follow the instructions in [this repository](https://github.com/SonyCSLParis/ControlLight) to control the LEDs.
{: .important}

<p align="center">
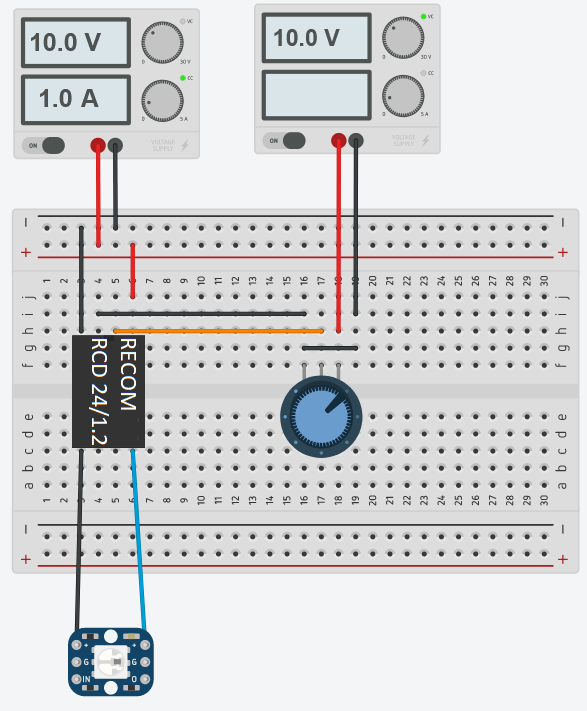
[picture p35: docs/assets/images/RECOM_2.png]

</p>

### Assembly and test

Mount the blue and purple LEDs on the UC2 star holder according to [UC2 documentation](https://github.com/openUC2/UC2-GIT/tree/master/CAD/ASSEMBLY_CUBE_LED). Add the lens mounted on the holder in front of the LED, and the filter mounted on the filter holder. 

<p align="center">
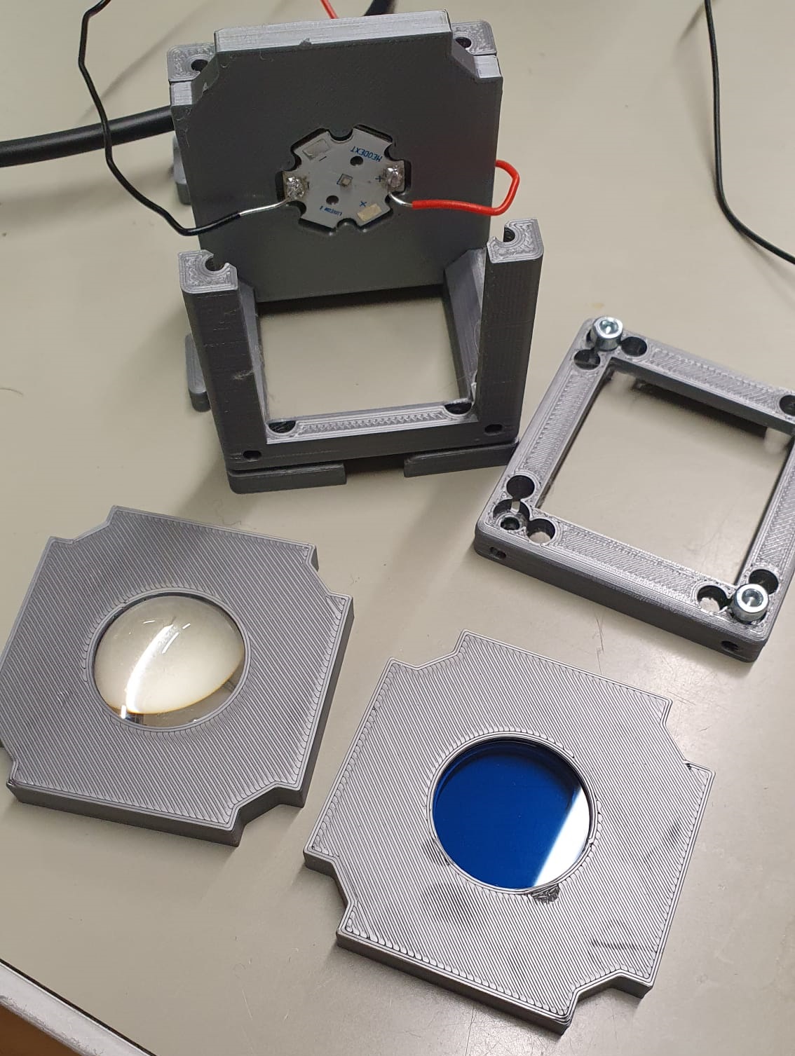
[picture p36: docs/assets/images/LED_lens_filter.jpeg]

</p>

<p align="center">
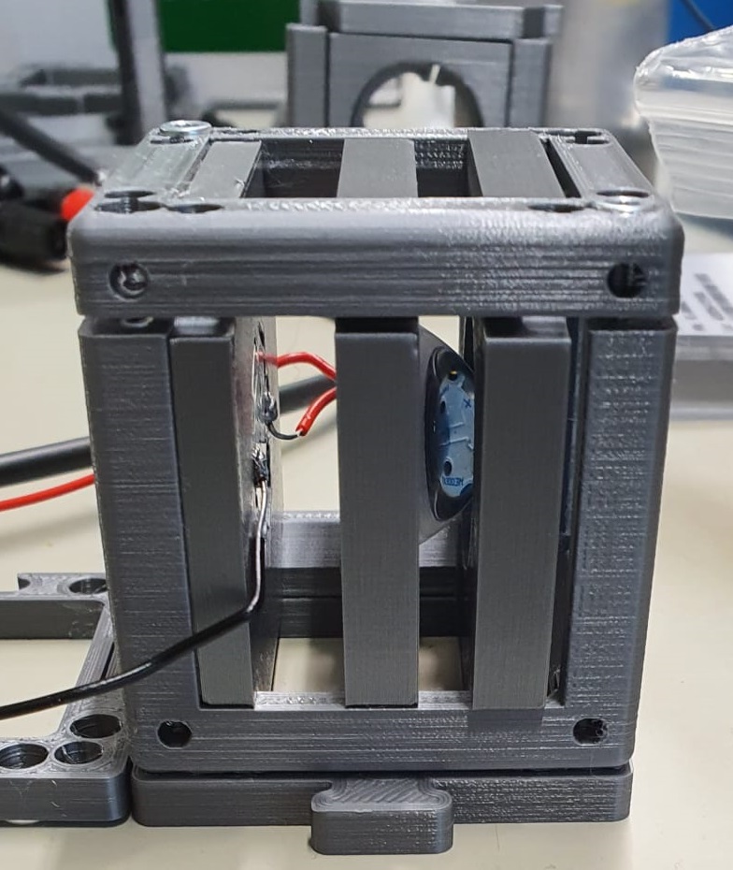
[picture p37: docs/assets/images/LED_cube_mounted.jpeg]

</p>

Make sure that you can observe the image of the chip on a white surface

<p align="center">
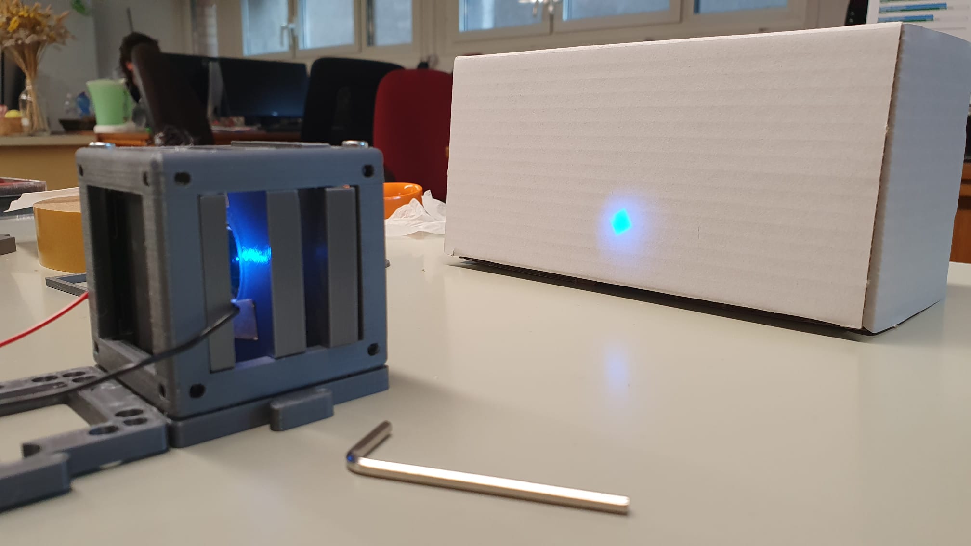
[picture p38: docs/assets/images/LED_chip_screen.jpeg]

</p>

Notes: the 3 mounts don't hold still once the base cube it closed. We had to use double-sided tape to fix the LED mount. One other option is to increase the size of the mount slightly to tight it with the screws when closing the cube. The clamp to hold the filter works fine but is not sufficient to hold the lens which has a different geometry. We designed a new lens holder that includes threading compatible with Thorlabs holders (1 inch) [HERE](XXX).

### LED combination

Mount the dichroic filter on the dichroic filter holder accroding to [UC2 documentation](https://github.com/openUC2/UC2-GIT/tree/master/CAD/ASSEMBLY_CUBE_Dichroic_Beamsplitter)

<p align="center">
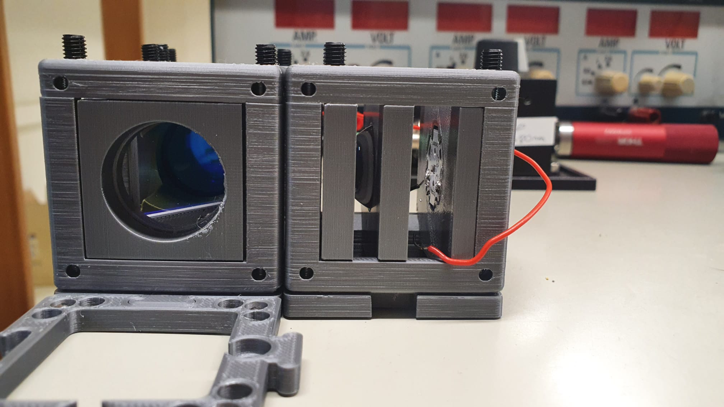
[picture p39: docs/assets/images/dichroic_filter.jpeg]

</p>

Combine the two LEDs with the dichroic filter according to this scheme: 

<p align="center">
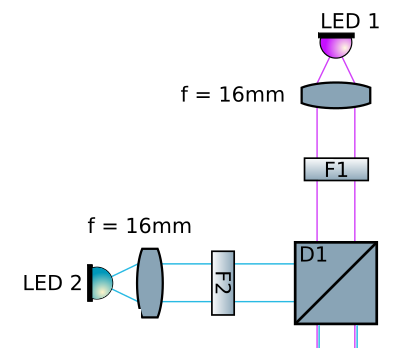
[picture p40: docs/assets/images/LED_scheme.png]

</p>
 
 With [LED 1](https://www.mouser.fr/ProductDetail/997-LHUV0405A065), [LED 2](https://www.mouser.fr/ProductDetail/997-LXZ1PB01), [F1](https://www.comaroptics.com/components/filters/glass-colour-filters), [F2](https://www.comaroptics.com/components/filters/glass-colour-filters), [D1](https://www.comaroptics.com/components/filters/dichroic-filters/long-pass-dichroic-filters), [lens](https://www.thorlabs.de/thorproduct.cfm?partnumber=ACL25416U).

### Optical fiber injection

 The 2 LEDs are combined, however the size of the light beam is on the centimeter scale, but the optical fiber's aperture is 400µm. We use a microscope objective to reach the spot size required to inject in the fiber. (for now: 40x/0.65)

 Prepare the 3D parts for the fiber injection: XY fine displacement [objective holder](https://github.com/openUC2/UC2_OpenFiberCoupler/blob/main/STL/Application_OpenFiberCoupling_20_Cube_Inser_Flexuremanipulator_v3.stl) and lens holder to hold the [SMA fiber adapter](https://www.thorlabs.com/thorproduct.cfm?partnumber=SM1SMA#ad-image-0). You can find more info on [UC2 documentation for fiber coupler](https://github.com/openUC2/UC2_OpenFiberCoupler). Mount the objective in one cube and the fiber holder in another and assemble them.

 <p align="center">
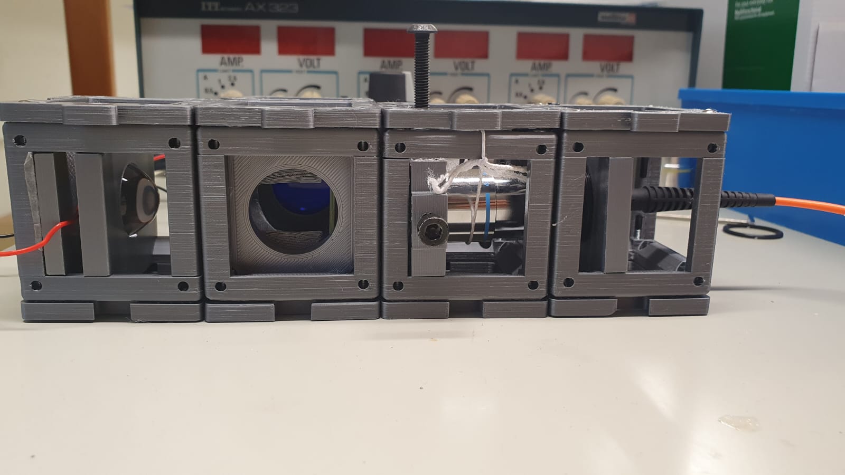
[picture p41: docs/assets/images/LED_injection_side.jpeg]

</p>

 <p align="center">
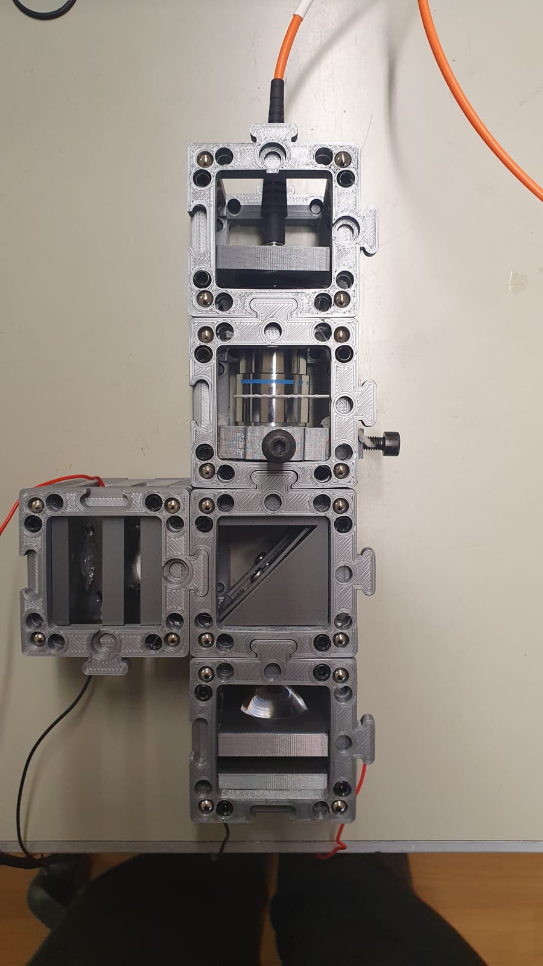
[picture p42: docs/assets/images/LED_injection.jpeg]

</p>

Note: The XY objective holder is great ! The only issue is that the rest position is centered and the screws only allow positive X or Y displacement. We attached an elastic so that the rest position is tight to the corner (minimal X and Y position). That way it is possible to explore the whole X-Y displacement space allowed by the 3D piece with only 2 screws.

 <p align="center">

</p>

Adjust the focal distances so that the spot from the LEDs matches the entrance of the microscope objective and the output of the objective matches the aperture of the fiber. (TODO: give more details here)

Check the output of the fiber and the homogeneity of the spot. The blue light is brighter so you can play with the potentiometers to see the 2 colors separately. 

 <p align="center">
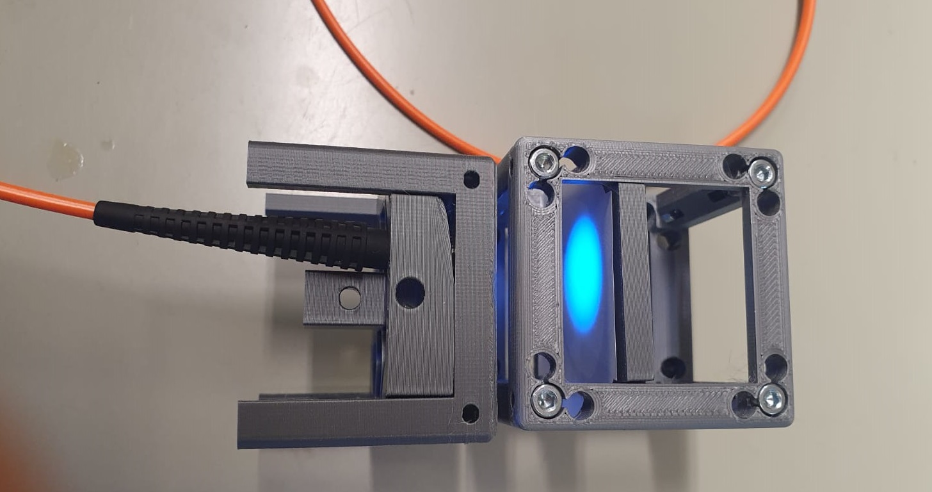
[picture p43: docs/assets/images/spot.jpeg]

</p>

# Imaging

1 - Start to build the second part of the microscope : connect the other end of the fiber on an other UC2 cube.

2 - Mount a dichroïc filter on a dichroïc holder cube ([UC2 documentation](https://github.com/openUC2/UC2-GIT/tree/master/CAD/ASSEMBLY_CUBE_Dichroic_Beamsplitter)) and place it after the fiber according to the schema :

<p align="center">
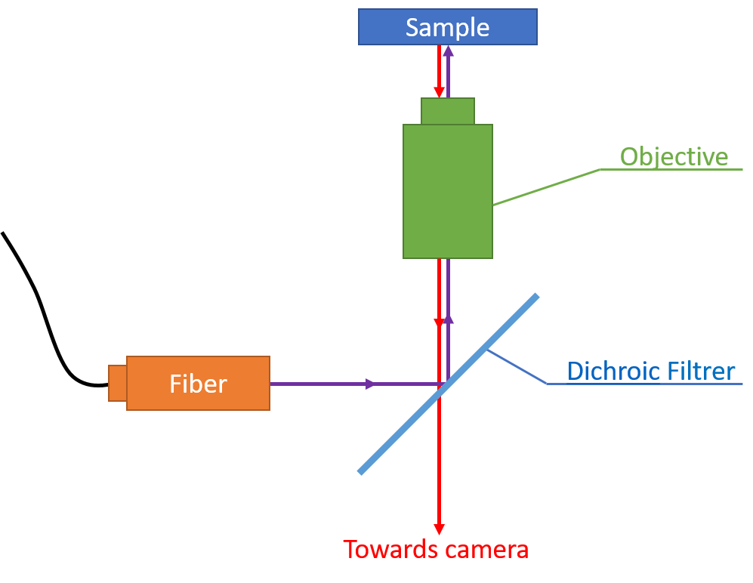
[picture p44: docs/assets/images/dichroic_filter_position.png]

</p>

3 - Construct the upper part of the scheme with the objective and the sample holder : we use XY fine displacement [objective holder](https://github.com/openUC2/UC2_OpenFiberCoupler/blob/main/STL/Application_OpenFiberCoupling_20_Cube_Inser_Flexuremanipulator_v3.stl) in one cube followed by [Generic sample holder](https://github.com/openUC2/UC2-GIT/tree/master/CAD/ASSEMBLY_CUBE_Sample_Holder) in another cube. 

<p align="center">
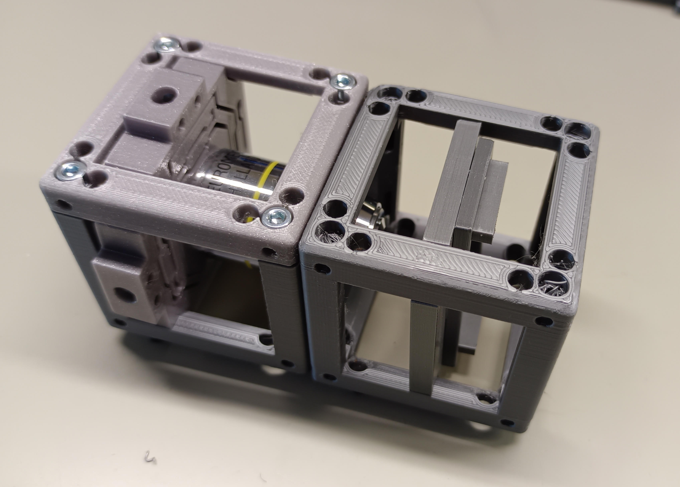
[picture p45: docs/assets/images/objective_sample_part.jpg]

</p>

4 - Combine the dichroïc filter and the objective-sample part. The dichroïc filter transmits light below the cut-off wavelength and reflects ligth above the cut-off. The fluorescence emission has a higher emission wavelength than the excitation. The incomming light from the fiber will be reflected by the dichroïc filtrer and go through the objective. Then the light emitted by the sample will be collected by the objective and pass the dichroïc filter without reflexion.

<p align="center">
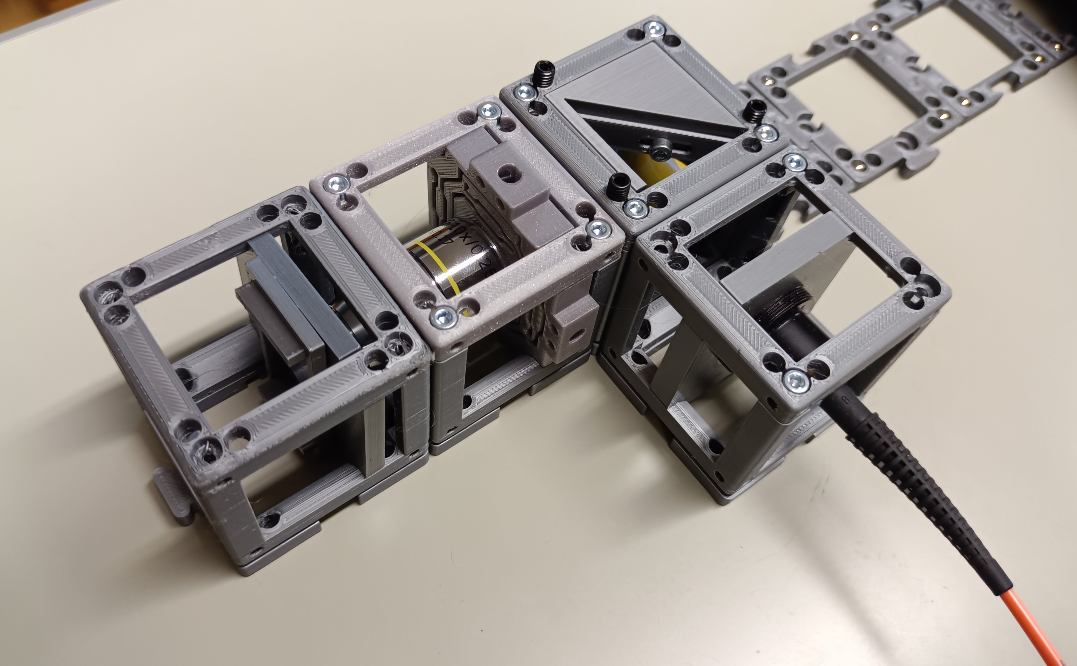
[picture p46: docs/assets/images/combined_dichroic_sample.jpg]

</p>

5 - Print your camera 3D holder model from the [git](https://github.com/openUC2/UC2-GIT/tree/master/CAD) (Search with Ctrl+F), and mount your camera in it. We use a Daheng MER2-503-36U3C camera with [Camera Cube (Allied Vision Alvium)](https://github.com/openUC2/UC2-GIT/tree/master/CAD/ASSEMBLY_CUBE_Daheng_Imaging).
On the Daheng camera, the fixation consist on three screws :
<p align="center">
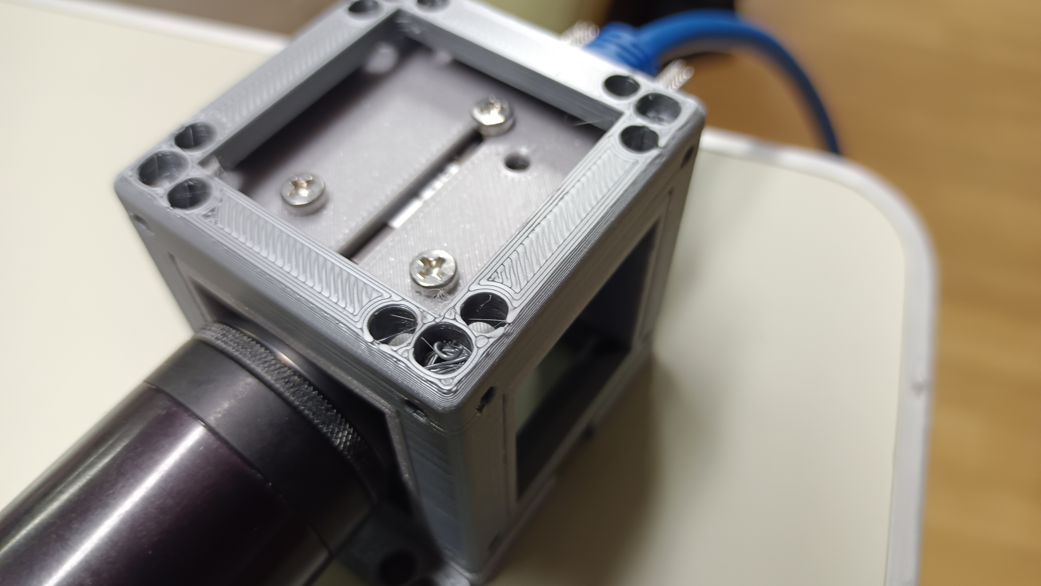
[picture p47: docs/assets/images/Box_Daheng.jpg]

</p>

Note : We also use an IDS camera, and since there is not a camera holder for it, we use the [Camera Insert Allied Vision Alvium adjustable](https://github.com/openUC2/UC2-GIT/blob/master/CAD/RAW/STL/20_Cube_insert_AlliedVision_Alvium_adjustable_v3.stl).

6 - Mount an adapted lens on the camera (we used a focal of f = 150 mm). Position the lens to conjugat it with the camra sensr: to do so, observe a net image of an object positionned 10 meters away from the camera. Then, align the lens and camera with the microscope objective and move the sample along the Z-axis to adjust the focus. To observe the sample, you may need to adjust your's camera parameters, like the exposure time and the gain. 

>You can follow the instructions in [this repository](https://github.com/SonyCSLParis/Motorized-stage) to automate the movement of the sample.
{: .important}

<p align="center">
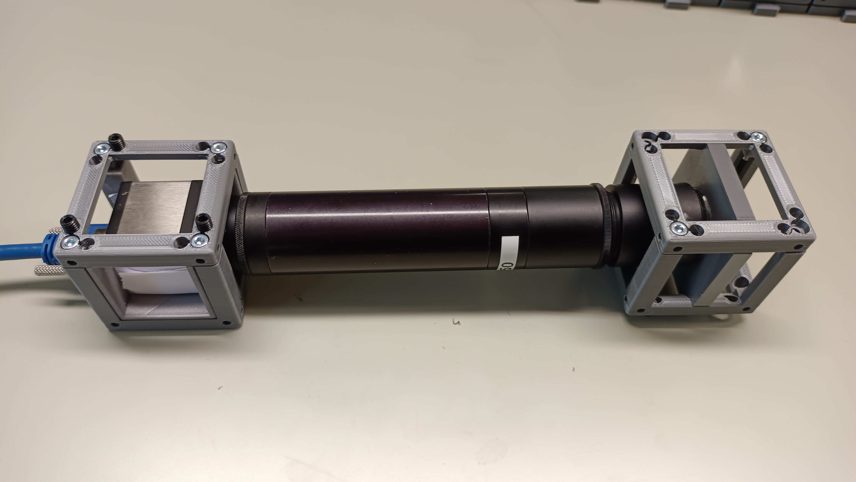
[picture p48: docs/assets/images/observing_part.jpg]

</p>
Note : Since the lens is heavy, we put a UC2 cube at the end of it with a lens holder to keep it straight.

The 2nd part of the microscope should look like that :
<p align="center">
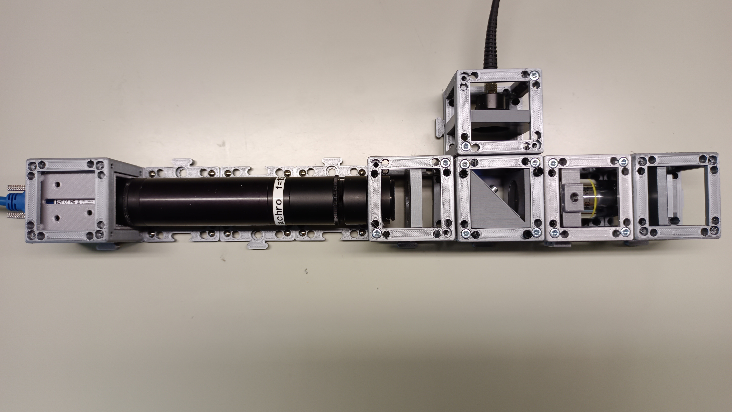
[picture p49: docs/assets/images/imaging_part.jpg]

</p>

The final result should be looking like this :
<p align="center">
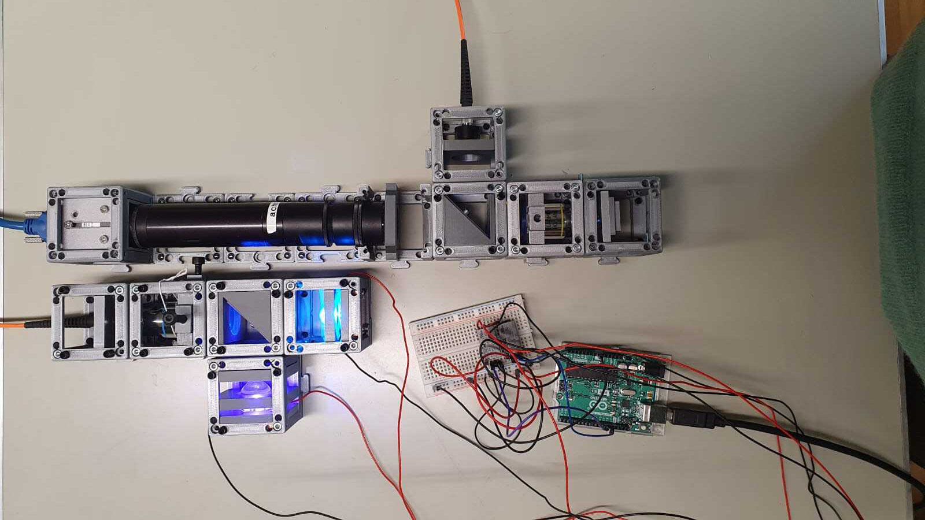
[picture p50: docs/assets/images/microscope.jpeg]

</p>

With this microscope, with managed to observe some samples using the software provided by the camera manufacturer :
<p align="center">
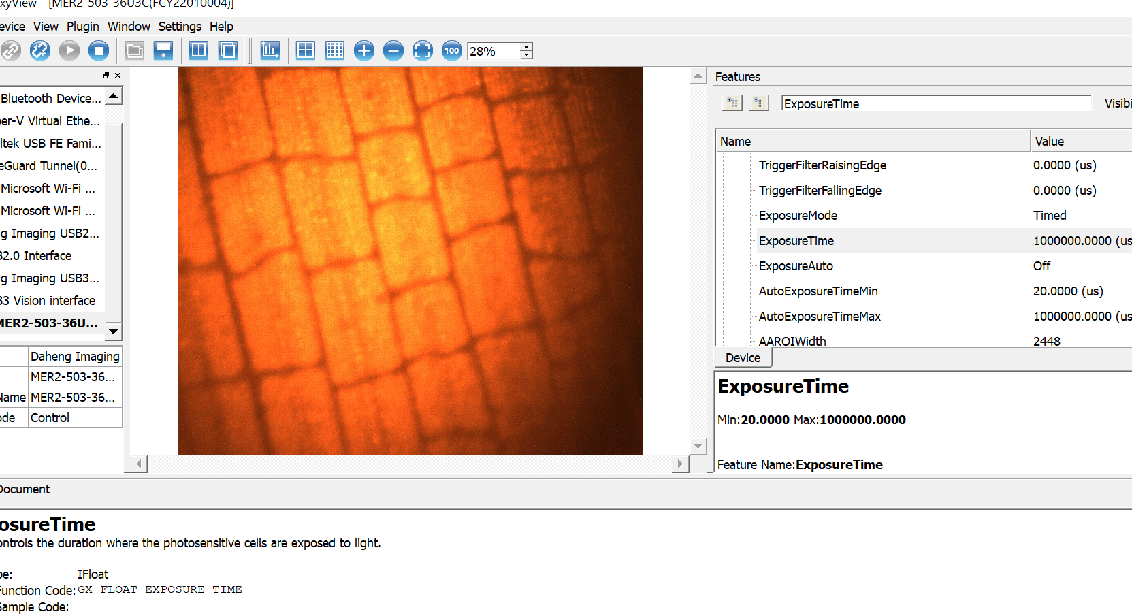
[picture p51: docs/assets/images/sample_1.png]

</p>
<p align="center">
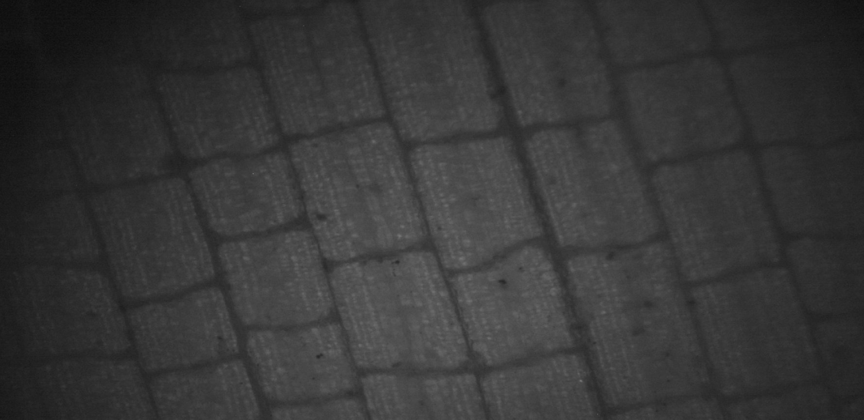
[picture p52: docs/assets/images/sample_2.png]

</p>

>You can follow the instructions in [this repository](https://github.com/SonyCSLParis/ControlCamera) to control the camera using Python.
{: .important}

## Example of use

For an example of project using this hardware you can refer to [this page](https://alienor134.github.io/UC2_Fluorescence_microscope/docs/example)

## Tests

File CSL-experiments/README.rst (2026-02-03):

Experimental framework based on Sacred
======
The principle of Sacred is to store the experiment data and metadata in a file  that can be stored in a database. Here we used the noSQL framework with MongoDB. There are numerous aspects to Sacred detailed in the `original publication <https://conference.scipy.org/proceedings/scipy2017/klaus_greff.html>`_ including: 

#. Save code and imported code used to launch the experiment
#. View experiment parameter set
#. Save log
#. Draw graphs in the database and access the raw data (metrics)
#. Save numerous file types (artifacts)
#. Compare experiments: results/code difference/metadata difference

Install Sacred: 
=================

All the information about Sacred are here: `visit Sacred <https://github.com/IDSIA/sacred>`_

Install the database 
=================

Download `MongoDB <https://www.mongodb.com/try/download/community>`_
Create a new database called "sacred" (no caps).

Web interface
=================

All the information about Omniboard are here: `visit Omniboard <https://github.com/vivekratnavel/omniboard>`_)

in the command line type: 

``npm install -g omniboard``

To launch omniboard: 
```omniboard -m 127.0.0.1:27017:sacred```

To open the interface connect to : http://localhost:9000/sacred

![](Images/2023-02-06-10-57-11.png)

Install the database quiery tool: 
=================

All the information about Incense are here: `visit Incense <https://github.com/JarnoRFB/incense>`_)

Example of adaptation of [CSL-lights](XXX)
-------
+-----------------------------------------------+--------------------------------------------------------+
| **Script to control a light source**          | **The same script as Sacred experiment**               |
+===============================================+========================================================+
| .. code:: python                              | .. code:: python                                       |
|                                               |                                                        |
|   from serial import Serial                   |   from serial import Serial                            |
|   import CSLlight                             |   import CSLlight                                      |
|   arduino_port = "COM5"                       |   from sacred.observers import MongoObserver           |
|   sec = 1000 #conversion ms to s              |   from sacred import Experiment                        |
|   LED_param = {'pin':11,                      |   ex = Experiment('blink_LED')                         |
|   'offset':0.5*sec,                           |   ex.observers.append(MongoObserver(db_name = "demo")) |
|   'period': 5*sec,                            |                                                        |
|   'duration': 2*sec,                          |   @ex.config:                                          |
|   'analog_value': 255,                        |   def cfg():                                           |
|   }                                           |     arduino_port = "COM5"                              |
|                                               |     sec = 1000 #conversion ms to s                     |
|   link = Serial(arduino_port)                 |     LED_param = {'pin':11,                             |
|   CSLLight.add_digital_pulse(link, LED_param) |                  'offset':0.5*sec,                     |
|   CSLlight.start_measurement(link)            |                  'period': 5*sec,                      |
|   time.sleep(300)                             |                  'duration': 2*sec,                    |
|   CSLlight.stop_measurement(link)             |                  'analog_value': 255,                  |
|                                               |                  }                                     |
|                                               |   @ex.capture                                          |
|                                               |   def blink():                                         |
|                                               |     link = Serial(arduino_port)                        |
|                                               |     CSLLight.add_digital_pulse(link, LED_param)        |
|                                               |     CSLlight.start_measurement(link)                   |
|                                               |     time.sleep(300)                                    |
|                                               |     CSLlight.stop_measurement(link)                    |
|                                               |                                                        |
|                                               |   @ex.automain                                         |
|                                               |   def run():                                           |
|                                               |     blink()                                            |
|                                               |                                                        |
+-----------------------------------------------+--------------------------------------------------------+

Example of adaptation of [CSL-motors](XXX)
-------

+--------------------------------------------+--------------------------------------------------------+
| **Script to control a motor**              | **The same script as Sacred experiment**               |
+============================================+========================================================+
| .. code:: python                           | .. code:: python                                       |
|                                            |                                                        |
|   from CSLstage.CSLstage import CSLstage   |   from serial import Serial                            |
|                                            |   import CSLlight                                      |
|   arduino_port = "COM6"                    |   from sacred.observers import MongoObserver           |
|   gears = [1,1,1]                          |   from sacred import Experiment                        |
|   stage = CSLstage(arduino_port, gears)    |   ex = Experiment('blink_LED')                         |
|   #gearbox ratio of X, Y and Z axis        |   ex.observers.append(MongoObserver(db_name = "demo")) |
|   stage.handle_enable(1)                   |                                                        |
|   stage.move_dx(10)                        |   @ex.config:                                          |
|   stage.handle_enable(0)                   |   def cfg():                                           |
|   stage.reset()                            |     arduino_port = "COM5"                              |
|                                            |     gears = [1,1,1]                                    |
|                                            |                                                        |
|                                            |   @ex.capture                                          |
|                                            |   def get_stage():                                     |
|                                            |     stage = CSLstage(arduino_port, gears)              |
|                                            |                                                        |
|                                            |   @ex.automain                                         |
|                                            |   def run():                                           |
|                                            |     stage = get_stage()                                |
|                                            |                                                        |
|                                            |     stage.handle_enable(1)                             |
|                                            |     stage.move_dx(10)                                  |
|                                            |     stage.handle_enable(0)                             |
|                                            |     stage.reset()                                      |
|                                            |                                                        |
+--------------------------------------------+--------------------------------------------------------+

Example of adaptation of [CSL-camera](XXX)
-------

+---------------------------------------------------------------------+--------------------------------------------------------------+
| **Script to control a camera**                                      | **The same script as Sacred experiment**                     |
+=====================================================================+==============================================================+
| .. code:: python                                                    | .. code:: python                                             |
|                                                                     |                                                              |
|    from ControlCamera import ControlCamera                          |    from ControlCamera import ControlCamera                   |
|    cam_type = "MMConfig/Daheng.json"                                |                                                              |
|    update_param = {"Exposure": 150*1000,                            |    @ex.config                                                |
|                  "Gain": 23}                                        |    def config():                                             |
|    downscale = 5 #downscale the image to save                       |       cam_type = "MMConfig/Daheng.json"                      |
|    cam = ControlCamera(cam_type, update_param, downscale)           |       update_param = {"Exposure": 150*1000,                  |
|    N_im =  20                                                       |                  "Gain": 23}                                 |
|    cam.snap_video(N_im)                                             |                                                              |
|    video, timing = save_video("save_folder")                        |       downscale = 5 #downscale the image to save             |
|    cam.reset()                                                      |       N_im =  20                                             |
|                                                                     |    @ex.capture                                               |
|                                                                     |    def get_camera():                                         |
|                                                                     |       cam = ControlCamera(cam_type, update_param, downscale) |
|                                                                     |                                                              |
|                                                                     |    @ex.automain                                              |
|                                                                     |    def run(N_im):                                            |
|                                                                     |       cam.snap_video(N_im)                                   |
|                                                                     |       video, timing = save_video(save_folder, _run)          |
+---------------------------------------------------------------------+--------------------------------------------------------------+

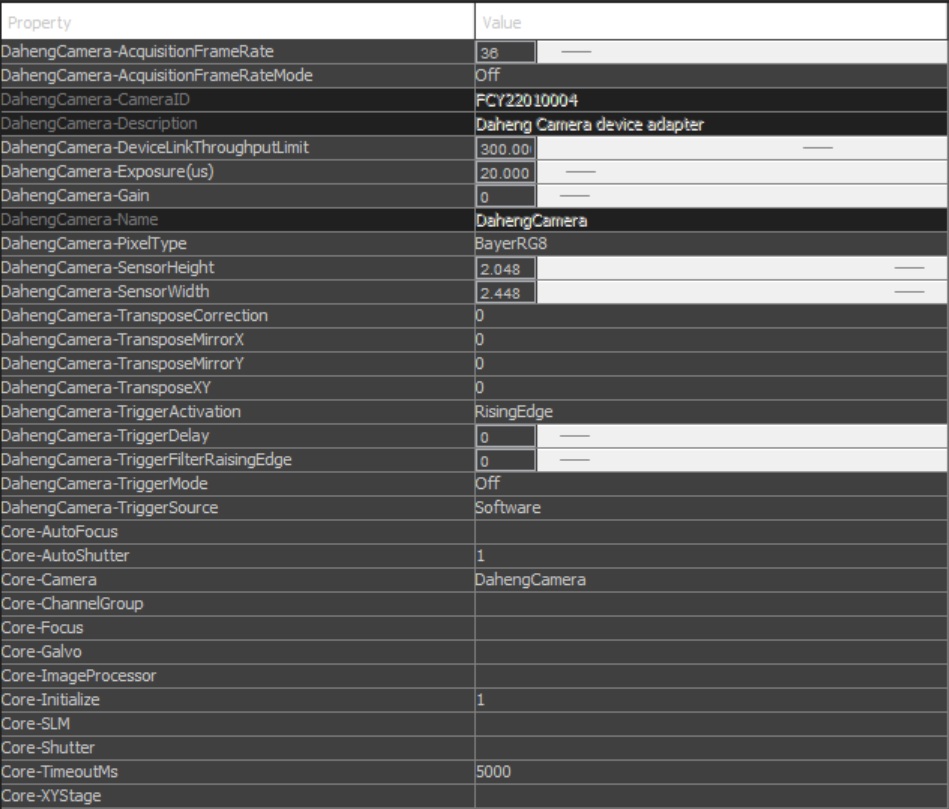
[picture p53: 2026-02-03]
CSL-experiments/MMconfig/Daheng_config_MM.jpg

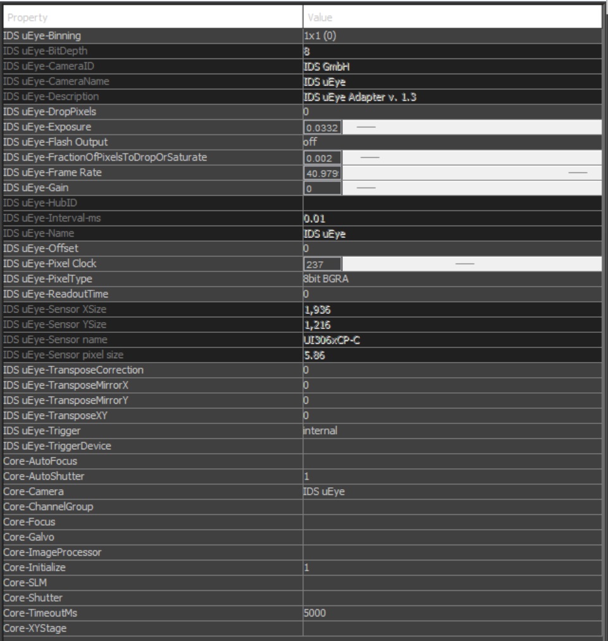
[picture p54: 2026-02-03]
CSL-experiments/MMconfig/UEye_config_uM.jpg

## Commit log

2022-03-10 LED assembly
2022-05-05 Added an image to illustrate the combinaise of the dichroic filter and the sample part
2022-05-24 added stl files and arduino
    [20_Cube_Insert_Beamsplittercube_Base_25x35_v3.stl, 20_Cube_Insert_Beamsplittercube_Retainring_25mm_v3.stl, 20_Cube_Insert_Sample_clamp_v3.stl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]
2025-04-29 case issue
2025-04-29 solve case issue
2026-02-03 update control camera
2026-02-03 submodule control motors
2026-02-03 example of experiments
    [Andor.cfg, Daheng.cfg, UEye.cfg]
2026-02-03 renaming folders, updating doc
    [00_Alvium_Step_USB90_S-Mount_ClosedHousing_2019-Mar-28.ipt, 00_BallMagnets_5mm_single.ipt, 00_Chroma_Dichroic_25x,3x1.ipt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]
2026-02-03 add missing design files
    [00_Alvium_Step_USB90_S-Mount_ClosedHousing_2019-Mar-28.ipt, 00_BallMagnets_5mm_single.ipt, 00_Chroma_Dichroic_25x,3x1.ipt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]
2026-02-04 submodule motor update
2026-02-04 submodule camera update

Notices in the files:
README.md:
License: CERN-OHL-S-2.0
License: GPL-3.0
